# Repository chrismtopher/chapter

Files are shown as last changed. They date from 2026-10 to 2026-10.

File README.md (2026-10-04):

# Chapter Player for Audiobookshelf



A simple Raspberry Pi friendly Chapter player for Audiobookshelf.

Current release: **[v0.3.11](https://github.com/chrismtopher/chapter/releases/tag/v0.3.11)**

Chapter Player for Audiobookshelf is an independent third-party project and is not affiliated with or supported by the Audiobookshelf project.

Chapter is a native Linux appliance app built with Python and GStreamer. It signs in to Audiobookshelf with a dedicated user account, securely stores the server-issued tokens, shows a simple two-line OLED library and playback interface, resumes from Audiobookshelf progress, and syncs progress back while listening.

The target device is a small enclosure with a 2.08 inch SH1122 SPI OLED, two KY-040 rotary encoders, a MAX98357A I2S amp, and an internal speaker.

## Quick Install

Flash Raspberry Pi OS Lite onto a Raspberry Pi Zero 2 W/WH, enable SSH, and connect to the Pi. The recommended setup username is `chapter` and hostname is `chapter-player`.

Then run:

```bash
curl -fsSL https://raw.githubusercontent.com/chrismtopher/chapter/v0.3.11/scripts/install-raspberry-pi.sh | bash
sudo reboot
```

The installer handles the software setup:

- system packages
- project clone/update in `/home/chapter/audiobookshelf-player`
- SPI enablement
- MAX98357A I2S audio and ALSA config
- setup web page service
- OLED service and boot splash
- port 80 setup-page proxy
- captive portal DNS helper
- Bluetooth unblock helper
- BlueALSA Bluetooth audio backend

For the complete hardware, flashing, wiring, setup, and troubleshooting walkthrough, see the [Raspberry Pi Zero 2 W install guide](docs/raspberry-pi-zero-2w-install.md).

## Hardware

Recommended build:

- Raspberry Pi Zero 2 WH, or Raspberry Pi Zero 2 W with a soldered 40-pin header
- 16 GB or larger microSD card
- Regulated 5 V power supply rated for at least 2 A; see the install guide for the Adafruit 5993's 1.5 A power-path limitation
- 2.08 inch 256x64 SH1122 SPI OLED
- Two KY-040 rotary encoder modules
- MAX98357A I2S mono amplifier breakout
- 4 ohm speaker
- 1.5 A inline fuse on the USB-C 5 V positive lead
- 3 mm warm-white power indicator LED for the lower-right front-cover hole
- Cross-connect wires for component wiring

The wiring tables are in the [install guide](docs/raspberry-pi-zero-2w-install.md#wire-the-hardware).

Purchase links for the recommended parts are in [docs/hardware-links.md](docs/hardware-links.md).

Printable case files are in [hardware/case](hardware/case).

## Setup

After installation and reboot, open the setup page from a phone or computer on the same network:

```text
http://chapter-player.local
```

If the player is not connected to Wi-Fi, it starts an open setup hotspot:

```text
Network:  Chapter-Setup
Password: none
Page:     http://10.42.0.1
```

The setup page lets you enter your Wi-Fi details and log the player into Audiobookshelf. Create a dedicated Audiobookshelf user for the player and restrict that user to the appropriate library or tags.

For a simple handout, see the [first boot one-sheet](docs/first-boot-one-sheet.md).

For a package-style quick start card, open the [PDF](docs/first-boot-quick-start.pdf) or [JPG](docs/first-boot-quick-start.jpg).

## Controls

- Turn the Select knob to browse books.
- Click the Select knob to choose.
- Turn the Volume knob to change volume.
- Click the Volume knob to mute or unmute.
- Hold the Volume knob for 10 seconds to show the setup address.
- Hold the Select knob for 3 seconds to open the Bluetooth menu.
- In the Bluetooth menu, turn the Select knob to choose `Enable`, `Disable`, `Pair`, `Unpair`, or `Back`, then click to select.
- To pair a speaker or headphones, put the device in pairing mode, choose `Pair`, wait for the device list, turn to the device name, and click to connect.
- Parents can enable `Spoken navigation` on the Settings tab to have the player read highlighted book titles and controls aloud. It is disabled by default.
- With spoken navigation enabled, Volume-knob changes are announced at 10% intervals, volume stops at 10%, and pressing the Volume knob does not mute the player.

## Features

- Two-line SH1122 OLED library and playback UI
- Select and Volume rotary controls
- Internal speaker playback through GStreamer
- Audiobookshelf login through the local setup page
- Admin web page player controls, including play/pause and volume
- Configurable library ordering by title or author last name
- Optional offline spoken navigation for book titles and controls using a tuned eSpeak NG voice
- System-tab software update checks and one-button stable release installation
- Resume from Audiobookshelf progress
- Periodic progress sync back to Audiobookshelf
- Multi-file audiobook playback
- Continue/start-over prompt when a book has listening history
- Wi-Fi setup fallback hotspot

## Security

The administration page is intentionally passwordless and is intended only for a trusted private home network. Anyone who can reach it can control or reset the player. Do not expose the player to the internet, configure router port forwarding, or connect it to an untrusted network.

CSRF protection prevents unrelated websites from submitting commands through your browser, but it does not authenticate people already connected to the same network. Use a dedicated, restricted Audiobookshelf account for the player. See the full [security policy](SECURITY.md) for details and vulnerability-reporting instructions.

## Development

Run the test suite with:

```bash
python3 -m unittest discover -s tests
```

Run the isolated Raspberry Pi OS Lite installer simulation with:

```bash
tests/mock_raspberry_pi_install.sh
```

See [docs/appliance-design.md](docs/appliance-design.md) for hardware notes, UI behavior, and future direction.

Release history is recorded in [CHANGELOG.md](CHANGELOG.md).

## License

This project is open source under the terms of the [MIT License](LICENSE).

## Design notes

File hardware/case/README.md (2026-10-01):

# Chapter Case

Printable STL files for the Chapter Player enclosure.

## Files

- [stl/chapter-case-front-v5.stl](stl/chapter-case-front-v5.stl) - front case shell
- [stl/chapter-case-back-v5.stl](stl/chapter-case-back-v5.stl) - back case shell
- [stl/chapter-case-knob-v5.stl](stl/chapter-case-knob-v5.stl) - rotary encoder knob

## Assembly Diagrams

- [case-top-select-volume-reference.png](case-top-select-volume-reference.png) - CAD reference showing the top of the case and the `SELECT` and `VOLUME` labels
- [case-front-cover-backside-oled-layout.jpg](case-front-cover-backside-oled-layout.jpg) - annotated CAD view of the back side of the front cover showing OLED installation
- [case-back-interior-layout.jpg](case-back-interior-layout.jpg) - annotated CAD view into the case back showing heat press insert bosses and hardware mounting areas
- [case-rotary-encoder-mount-layout.jpg](case-rotary-encoder-mount-layout.jpg) - annotated CAD view from the x=0/front-side angle showing the two KY-040 rotary encoder mounts

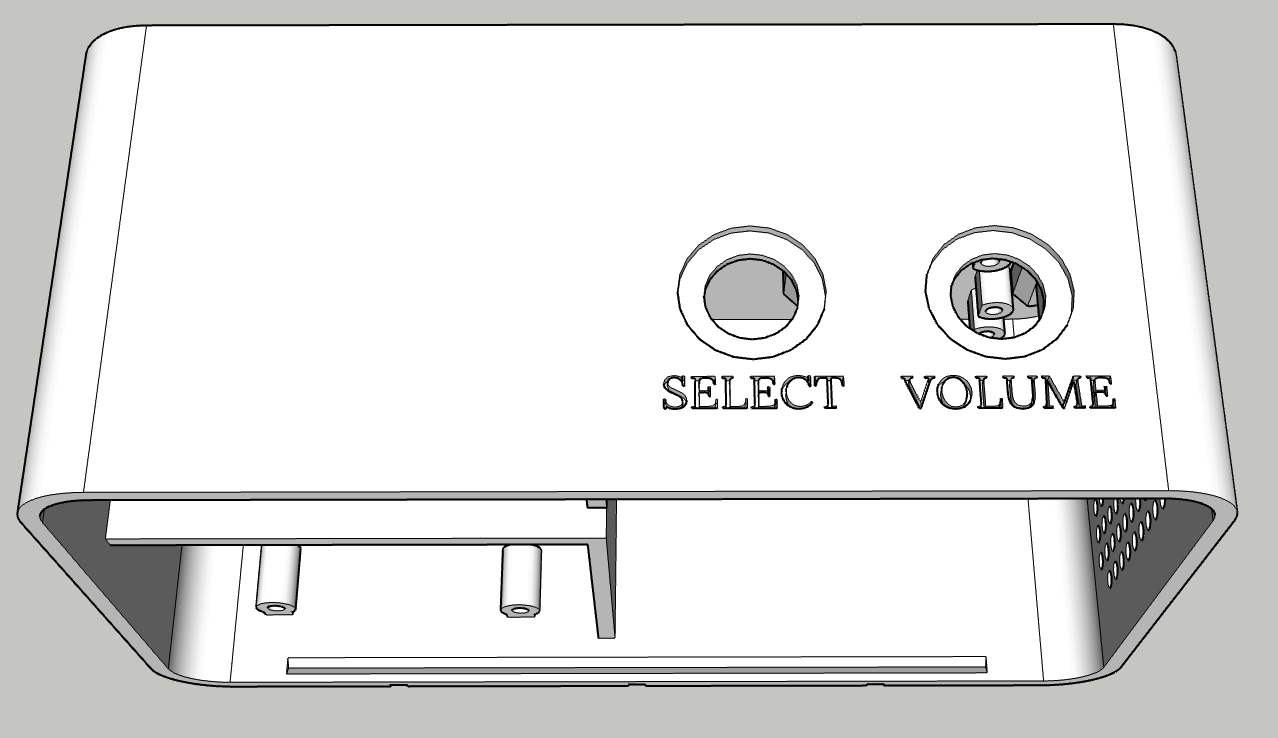
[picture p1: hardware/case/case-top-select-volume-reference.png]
Top of case with Select and Volume labels


Use this CAD view as the reference for the top of the finished case. The left opening is labeled `SELECT` and the right opening is labeled `VOLUME`, matching the control names used throughout the Chapter documentation.

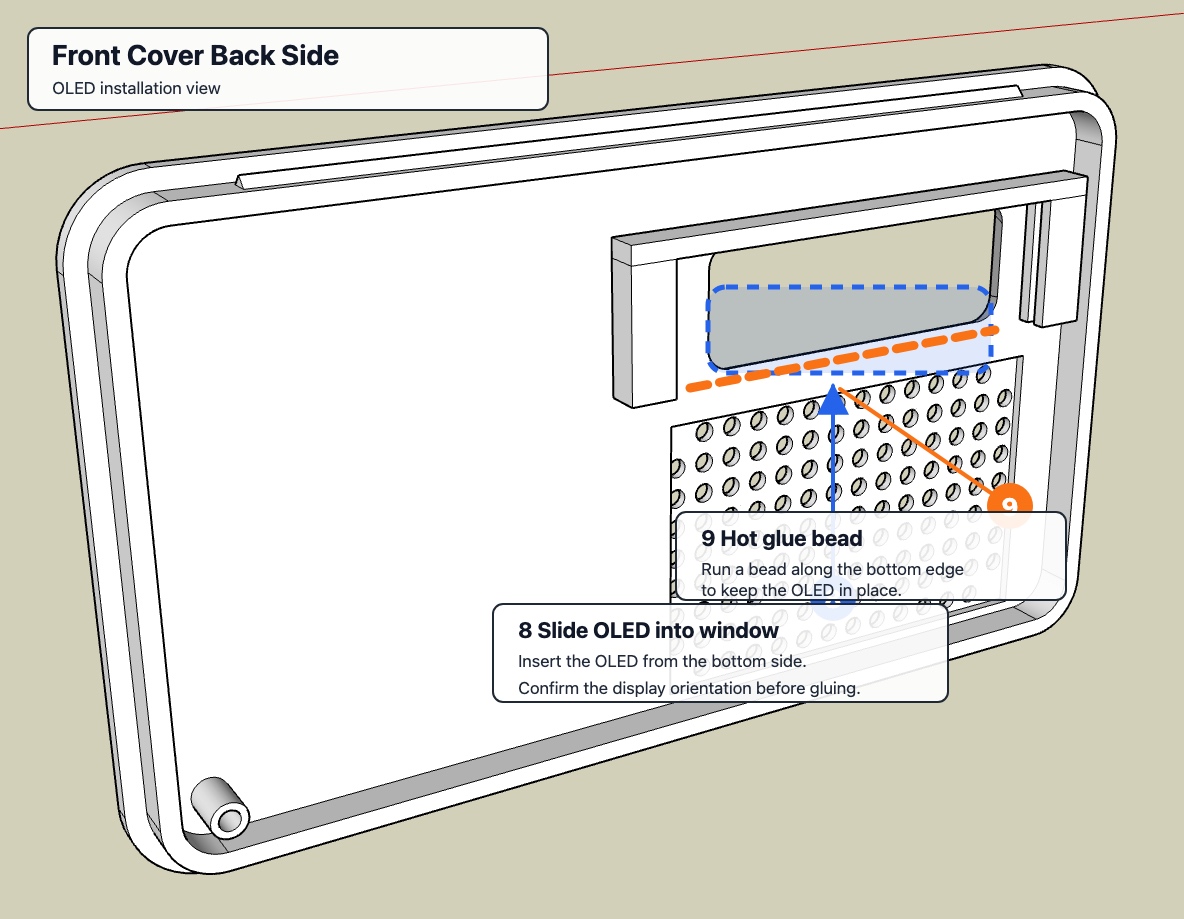
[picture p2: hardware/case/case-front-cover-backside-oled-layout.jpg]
Front cover back side OLED layout


In the front cover back-side diagram, blue `8` marks the OLED window. Slide the OLED into the window from the bottom. After you confirm the OLED is in the correct orientation, run a small bead of hot glue along the bottom edge, marked in orange as `9`, to keep it in place.

The small hole at the lower-right of the front cover, as viewed from the outside, is for the 3 mm warm-white power indicator LED. Insert the LED into the hole from the back of the cover and secure it with a small dab of hot glue. The build uses the 5-6 V [Dioramo 13240](https://dioramo.com/products/13240); see the [install guide](../../docs/raspberry-pi-zero-2w-install.md#power-indicator-led) for its power wiring.

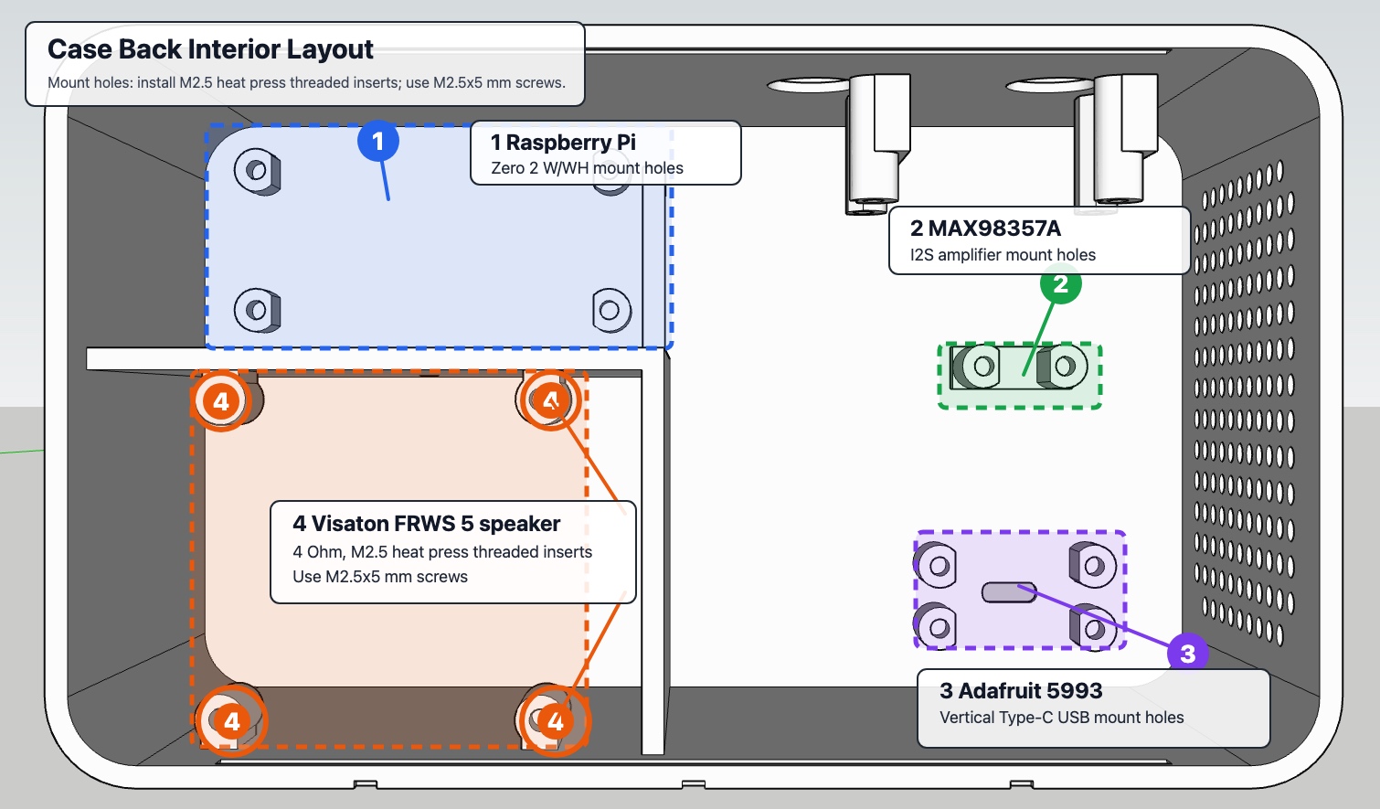
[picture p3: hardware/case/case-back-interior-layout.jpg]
Case back interior layout


In the diagram, orange `4` marks the speaker mounting bosses for a Visaton FRWS 5 - 4 Ohm speaker. Install M2.5 heat press threaded inserts in the highlighted mounting holes and use M2.5x5 mm screws for mounting components.

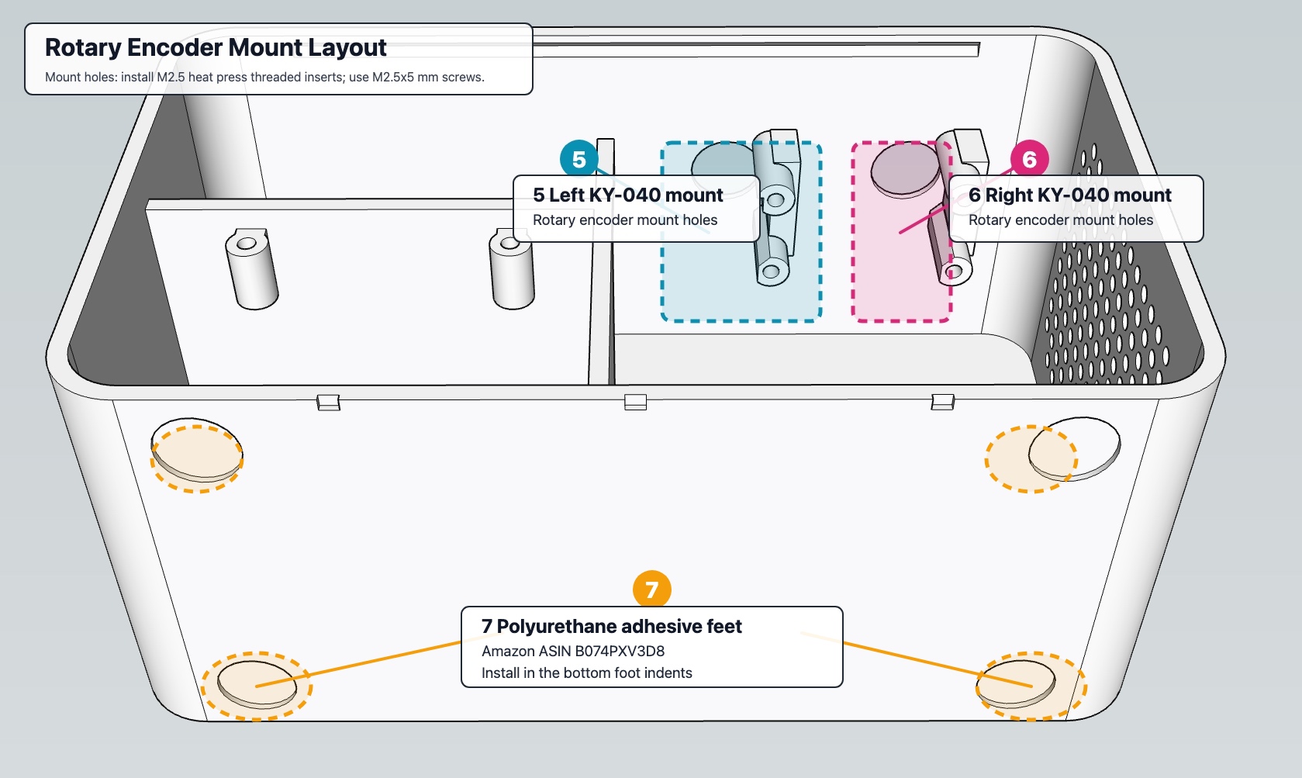
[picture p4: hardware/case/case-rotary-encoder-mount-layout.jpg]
Rotary encoder mount layout


In the rotary encoder diagram, `5` and `6` mark the KY-040 module mounts for the Select and Volume knobs on the inner front wall.

Orange `7` marks the bottom foot indents. Install polyurethane adhesive feet in those indents; the build uses [Amazon ASIN B074PXV3D8](https://www.amazon.com/dp/B074PXV3D8?th=1).

The annotated JPGs use the CAD screenshots in [images/](images/) as their source views.

## Installing The Front Cover

Treat the front cover as the final assembly step. Before installing it, complete the wiring and software tests and confirm that the display, Select knob, Volume knob, speaker, power indicator, Wi-Fi, and playback all work correctly.

1. Arrange the internal wiring so no wire can be pinched between the front cover and the back of the case.
2. Place the front cover over the back of the case and align their edges.
3. Start at either the left or right side; engaging one side first is easier than trying to snap the entire cover into place at once.
4. Work around the perimeter with even hand pressure until the remaining tabs snap into place.
5. Check that the seam is even and fully seated on every side.

If a section is difficult to insert, a thin plastic spudger or similar non-marring tool can provide gentle leverage between the cover and the back of the case. Do not force the cover, use a metal screwdriver, or pry near wiring and printed snap tabs; stop and check alignment or trapped wires instead.

## Notes

These files are provided as the v5 case export. They are intended for the Raspberry Pi Zero 2 W/WH build described in the main install guide.

The exact print orientation, supports, material, and slicer settings may depend on your printer. If you remix the case, STEP or source CAD files are especially helpful for other builders.

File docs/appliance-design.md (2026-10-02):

# Appliance Design

This project is a small kid-friendly audiobook appliance. The released build works on its own with a built-in speaker and can optionally send audio to a paired Bluetooth speaker or headphones. Sonos and AirPlay output are not currently implemented.

## Recommended Hardware

### Core Device

- Lowest-cost target: Raspberry Pi Zero 2 W
- Easier development target: Raspberry Pi 4, 2GB RAM or better
- Raspberry Pi OS Lite
- 16GB or 32GB A1/A2 microSD card
- Good 5V power supply sized for the Pi, OLED, and speaker amp

Moving from a graphical touchscreen to a two-line OLED makes the Pi Zero 2 W realistic. A Pi 4 is still nicer while developing, but it is no longer required for the finished appliance.

### Display

- D-FLIFE 2.08 inch SH1122 SPI OLED
- 256x64 pixels
- 4-wire SPI
- 3.3V logic and power
- Two-line UI: title on top, context/action on bottom

This display changes the product shape: cover art should not be shown on-device. The app can still use Audiobookshelf cover metadata later for a web admin view or companion app.

### Controls

Use two KY-040 rotary encoder modules, labeled `Select` and `Volume` on the case:

- Select knob: browse books, choose continue/start-over, play/pause, and confirm chapter navigation.
- Volume knob: turn for volume, short-click for mute/unmute, and hold for 10 seconds to show the setup IP.

The KY-040 has `CLK`, `DT`, `SW`, `+`, and `GND` pins. Power each module from the Pi's 3.3V rail, not 5V, so its pull-ups never expose a Raspberry Pi GPIO input to 5V. If clockwise/counter-clockwise feels reversed after mounting, either swap `CLK` and `DT` or set the encoder's `reversed` flag in software.

### Internal Speaker

Use an I2S amplifier board rather than Bluetooth. I2S keeps the build self-contained and works cleanly even on Pi models with no analog audio jack.

Recommended parts:

- MAX98357A I2S mono amplifier breakout
- One Visaton FRWS 5 - 4 Ohm full-range speaker
- Small speaker grille or perforated enclosure area

For audiobook voice playback, one internal mono speaker is enough. A stereo I2S amp or bonnet is fine too, but it is not required.

### Speaker Chamber

Target a sealed chamber of about 0.2 to 0.35 liters net internal volume for the Visaton FRWS 5 - 4 Ohm. Bigger is fine if the enclosure allows it; smaller still works for speech, but it will sound thinner and more constrained.

Good internal dimensions:

- 70 mm x 70 mm x 45 mm = 0.22 liters
- 80 mm x 70 mm x 45 mm = 0.25 liters
- 80 mm x 80 mm x 50 mm = 0.32 liters

Keep the chamber empty except for the speaker and speaker wires. A small amount of acoustic damping material is okay if the chamber sounds boxy, but keep it away from the back of the speaker cone. Seal the speaker gasket and the wire pass-through.

## Playback Architecture

```text
Audiobookshelf API
    |
    | library, metadata, sessions, progress
    v
Kids Player UI
    |
    +-- OLED: SH1122 SPI two-line display
    |
    +-- Inputs: Select knob + Volume knob
    |
    +-- Local output: GStreamer -> I2S internal speaker
    |
    +-- Optional output: paired Bluetooth speaker or headphones
```

## Two-Line UI

### Library

```text
Top:    audiobook title
Bottom: By author
```

Turn the Select knob to move through titles. Click it to open the selected title.

### Continue or Start Over

```text
Top:    audiobook title
Bottom: Home | Continue | Start over
```

When the selected book has listening history, `Continue` is the default selection. Turn the Select knob to move between `Home`, `Continue`, and `Start over`, then click to choose. If the book has no listening history, show only `Home` and `Start`.

### Playing

```text
Top:    scrolling chapter title with remaining time at the upper-right
Bottom: Home | Prev | Play/Pause | Next
```

The Select knob moves left and right through the action row, stopping at the edges. Click it to choose the focused action. `Play/Pause` is focused by default when playback starts. `Prev` and `Next` ask for confirmation before changing chapters. Returning to `Home` while audio continues playing automatically returns to this playback screen after five seconds without input.

Long chapter titles scroll horizontally while the remaining-time display and bottom action row stay fixed.

### Chapter Confirmation

```text
Top:    Are you sure you want to listen to the previous/next chapter?
Bottom: Yes | No
```

Turn the Select knob to switch between `Yes` and `No`. Click to confirm. The prompt returns to the playback screen after five seconds without input.

### Volume

The Volume knob is global:

- Turn clockwise: volume up
- Turn counter-clockwise: volume down
- Short click: mute/unmute
- Hold for 10 seconds: show the setup web page IP address on the OLED for 5 seconds

The long hold should not also toggle mute.

When volume is adjusted, replace the current OLED screen with a temporary volume overlay:

```text
Top:    Volume, or Muted at zero
Bottom: rounded graphical fill bar
```

The overlay should update on every volume step, then return to the previous screen after a short timeout.
Each additional volume adjustment refreshes the timeout, so the overlay remains visible for a few seconds after the user stops turning the knob.

## Suggested GPIO Pinout

This pinout avoids the I2S pins used by the MAX98357A amplifier. `GPIO` values use BCM numbering; `Physical Pin` values identify positions on the 40-pin header.

| Part | Signal | GPIO | Physical Pin |
| --- | --- | ---: | ---: |
| OLED | VCC | 3.3V | 1 |
| OLED | GND | GND | 6 |
| OLED | SCLK | GPIO11/SCLK | 23 |
| OLED | SDIN/MOSI | GPIO10/MOSI | 19 |
| OLED | CS | GPIO8/CE0 | 24 |
| OLED | DC | GPIO24 | 18 |
| OLED | RES | GPIO25 | 22 |
| Select knob KY-040 | + | 3.3V | 1 |
| Select knob KY-040 | GND | GND | 9 |
| Select knob KY-040 | CLK | GPIO5 | 29 |
| Select knob KY-040 | DT | GPIO6 | 31 |
| Select knob KY-040 | SW | GPIO13 | 33 |
| Volume knob KY-040 | + | 3.3V | 17 |
| Volume knob KY-040 | GND | GND | 14 |
| Volume knob KY-040 | CLK | GPIO12 | 32 |
| Volume knob KY-040 | DT | GPIO16 | 36 |
| Volume knob KY-040 | SW | GPIO26 | 37 |
| I2S amp | VIN | 5V | 2 or 4 |
| I2S amp | GND | GND | Any available GND pin |
| I2S amp | BCLK | GPIO18 | 12 |
| I2S amp | LRCLK | GPIO19 | 35 |
| I2S amp | DIN | GPIO21 | 40 |
| I2S amp | SD | Not connected | - |
| Speaker | + / - | I2S amp speaker output | - |

The two KY-040 modules can share 3.3V and ground rails. The code also enables Raspberry Pi internal pull-ups; this is harmless when the KY-040 module already has pull-ups, provided the module is powered from 3.3V.

The MAX98357A speaker output is differential. Connect the speaker only between the amplifier's `+` and `-` speaker terminals; never connect either speaker terminal to Raspberry Pi ground. Leave the amplifier `SD` pad disconnected in the released build.

## USB-C Power

Use the Adafruit 5993 vertical USB-C breakout as the appliance's rear power port. Chapter uses this connector for power only; leave `D+`, `D-`, `CC`, and `SBU` unwired.

For power, solder the positive lead to either Adafruit 5993 pad labeled `VBUS` and the negative lead to either pad labeled `GND`. Its two breakout rows duplicate the same connections, so either matching pair may be used. `VBUS` carries raw USB 5 V. Use red wire for `VBUS` and black wire for `GND`, and do not use the `CC`, `SBU`, `D+`, or `D-` pads as power connections.

| Adafruit 5993 pad | Raspberry Pi Zero 2 WH | Notes |
| --- | --- | --- |
| `VBUS` (+5 V) | 5V header pin 2 or 4, or 5V test pad | Positive power lead; install a 1.5 A fuse in series. |
| `GND` (-) | GND header pin 6, or GND test pad | Negative power lead; connect to the Pi and amplifier common ground. |

Recommended fuse options:

- Bourns `MF-MSMF150-2`, 1.5A hold / 3A trip, 6V, 1812 SMD
- Littelfuse `1812L150ZR`, 1.5A hold / 3A trip, 8V, 1812 SMD
- Inline holder: [Amazon ASIN B0813Q4S6P](https://www.amazon.com/dp/B0813Q4S6P), fitted with the included 1.5 A fast-blow 5x20 mm fuse

Wire the fuse in series with USB-C `VBUS`, before the Pi and amplifier:

```text
USB-C VBUS -> 1.5 A fuse -> optional power switch -> Pi 5V / amp 5V
USB-C GND  -> Pi GND / amp GND
```

Do not put the fuse in series with `GND`, `D+`, or `D-`.

Adafruit specifies this breakout arrangement for 5 V at up to 1.5 A. Raspberry Pi recommends a 2 A-capable supply for the Zero 2 W, so the tested 5993 is the limiting part of this power path. If Chapter reports undervoltage, reboots at high volume, or behaves unreliably, replace the input path with a regulated 5 V solution rated for at least 2 A.

Powering through a 5 V header pin bypasses the Pi's normal input protection. Verify polarity and voltage before connecting power, and never power the appliance through the 5993 and the Pi's original `PWR IN` micro-USB port simultaneously.

The lower-right hole in the front cover is for a 3 mm warm-white power indicator. Insert the LED from the back and hold it in place with a small dab of hot glue. Splice it as a parallel branch across fused 5 V and ground between the USB-C port and Pi; never put the LED in series with the Pi's supply. The indicator lights immediately when USB power is present, before the OLED service is ready.

The specified [Dioramo 13240](https://dioramo.com/products/13240) is rated for 5-6 V and includes its current-limiting resistor. Connect its white-marked anode wire directly to fused 5 V and its black cathode wire to ground; no additional resistor is required.

The USB-C connector supplies power only. Continue to use Wi-Fi or the Pi's original USB data port for servicing the appliance.

## Setup Web Page

The player exposes a local setup page on port `47831`. The appliance can also install a port `80` proxy so people can browse without typing a port:

```text
http://raspberrypi.local
```

On boot, the setup service should run with Wi-Fi fallback enabled:

```bash
python3 -m abs_kids_player.setup_server --ensure-wifi
```

This depends on NetworkManager's `nmcli`. The automated installer installs the setup page as a root-owned system service so it can manage Wi-Fi and start after reboot without an SSH session.

If no Wi-Fi connection is active, the player starts a temporary setup hotspot:

```text
Network:  Chapter-Setup
Password: none
Page:     http://10.42.0.1
```

While the hotspot is active, the OLED should show:

```text
Top:    Connect to Chapter-Setup
Bottom: Browse to http://10.42.0.1
```

The setup page accepts home Wi-Fi credentials. After submitting, the player waits briefly so the browser can receive the response, then asks NetworkManager to join the selected Wi-Fi network.

The setup hotspot should be an open network. To improve captive portal behavior, install the NetworkManager dnsmasq shared-mode config from `deploy/audiobookshelf-player-captive-portal-dnsmasq.conf`. It resolves HTTP browser traffic on the setup hotspot to `10.42.0.1`, and the port `80` proxy returns the setup page for arbitrary HTTP GET paths. This should trigger captive portal prompts on many phones and laptops. HTTPS sites cannot be transparently redirected, so the OLED still shows the direct setup URL as a reliable fallback.

The page logs the player into Audiobookshelf with the selected user's username and password. The password is not stored. The player persists:

- Audiobookshelf server URL
- Returned access and refresh tokens
- Audiobookshelf username
- Resolved library ID

This lets a parent change which Audiobookshelf user the appliance uses without attaching a keyboard and display to the Pi.

To reveal the address without a monitor, hold the Volume knob for 10 seconds while the unit is powered on. The OLED should show the setup URL, such as `http://192.168.1.42`, for 5 seconds and then return to the previous screen.

The web interface shows separate status rows for Wi-Fi, Audiobookshelf, Bluetooth, and current playback. Its System tab shows the installed version, available software updates, reboot control, and device-reset control. The `/health` route exposes machine-readable status for diagnostics.

## Enclosure Notes

- Keep the speaker chamber separate from the Pi where possible.
- Leave airflow around the Pi and amplifier.
- Put the OLED, speaker grille, wordmark, and power indicator on the front cover.
- Mount the two rotary encoders on the top panel and label them `SELECT` and `VOLUME`.
- Keep ports reachable for service, but hide them from everyday use.
- Add a small service hatch for the microSD card if possible.

## Render Reference

Use the current 3D printed prototype as the visual reference for future renders:

- Matte off-white PLA body and front cover with visible fine print texture.
- Warm tan/brown printed knobs with ridged/scalloped edges and textured top faces.
- Two similarly sized, low-profile knobs on the top panel: `SELECT` on the left and `VOLUME` on the right.
- OLED window on the upper-left/front with a black recessed display area and rounded rectangular cutout.
- Lowercase `chapter` wordmark in warm brown on the upper-right/front.
- Small 3 mm power-indicator opening at the lower-right of the front cover.
- Speaker grille on the lower-left/front, made from a dense grid of round holes.
- Matching side ventilation/speaker-style hole grid on the right side panel.
- Soft rounded outer corners and a gently rounded front perimeter.
- Keep the render grounded as a real printed object, not a perfectly smooth injection-molded product.

## References

- SH1122 OLED module specs: https://www.displaymodule.com/products/2-08-inch-oled-graphic-monochrome-display-256x64-with-spi
- KY-040 rotary encoder module reference: https://componentindex.net/components/rotary-encoder/
- KY-040 Raspberry Pi wiring reference: https://sensorkit.joy-it.net/en/sensors/ky-040
- Adafruit MAX98357A Raspberry Pi wiring: https://learn.adafruit.com/adafruit-max98357-i2s-class-d-mono-amp/raspberry-pi-wiring
- Adafruit 5993 USB-C breakout: https://www.adafruit.com/product/5993

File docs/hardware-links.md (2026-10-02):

# Hardware Links

These links are the parts used for the Chapter Player build. Quantities are for one player.

Links may change over time; equivalent parts should also work if they match the specs in the install guide and wiring tables.

## Electronics

| Part | Qty | Link | Notes |
| --- | ---: | --- | --- |
| Raspberry Pi Zero 2 W/WH | 1 | [Adafruit product 6008](https://www.adafruit.com/product/6008) | Use a WH board or add a soldered 40-pin header. |
| 2.08 inch SH1122 SPI OLED | 1 | [Amazon ASIN B0D1V5YBXC](https://www.amazon.com/dp/B0D1V5YBXC) | 256x64 SPI OLED. |
| KY-040 rotary encoder module | 2 | [Amazon ASIN B07T3672VK](https://www.amazon.com/dp/B07T3672VK) | One for the Select knob and one for the Volume knob. |
| MAX98357A I2S mono amplifier breakout | 1 | [Amazon ASIN B0GF67KXC3](https://www.amazon.com/dp/B0GF67KXC3?th=1) | Drives the internal speaker. |
| Adafruit 5993 vertical USB-C breakout | 1 | [Adafruit product 5993](https://www.adafruit.com/product/5993) | Rear USB-C power port. Solder positive power to `VBUS` and negative power to `GND`; either duplicate pad row may be used. Leave all data pads disconnected. Adafruit specifies up to 1.5 A for this breakout arrangement. |
| Inline fuse holder and fuse | 1 | [Amazon ASIN B0813Q4S6P](https://www.amazon.com/dp/B0813Q4S6P) | Install the included **1.5 A fast-blow 5x20 mm fuse** in series on the positive lead. The linked assortment also contains unsuitable higher-current fuses, so verify the marking before installation. |
| 3 mm warm-white power indicator LED | 1 | [Dioramo 13240](https://dioramo.com/products/13240) | Fits the lower-right front-cover hole. This 5-6 V version includes its current-limiting resistor and connects directly across Chapter's fused 5 V and ground leads. |
| Visaton FRWS 5 - 4 Ohm full-range speaker | 1 | [Parts Express 292-7820](https://www.parts-express.com/Visaton-FRWS5-4-2-Full-Range-Speaker-4-Ohm-292-7820?quantity=1) | Internal speaker. |
| Cross-connect wiring | 1 set | [Amazon ASIN B01EV70C78](https://www.amazon.com/dp/B01EV70C78?th=1) | Used for wiring between the Raspberry Pi and the display, encoders, amp, USB-C board, and fuse. |

## Case Hardware

| Part | Qty | Link | Notes |
| --- | ---: | --- | --- |
| Polyurethane adhesive feet | 4 | [Amazon ASIN B074PXV3D8](https://www.amazon.com/dp/B074PXV3D8?th=1) | Install in the bottom foot indents shown in the case diagram. |
| M2.5 heat press threaded inserts | 18 | Source from your preferred hardware supplier | Install in the highlighted component mounting holes. |
| M2.5x5 mm screws | 18 | Source from your preferred hardware supplier | Used for mounting components into the heat press inserts. |
| Printed case front, back, and knobs | 1 set | [Case STL files](../hardware/case/) | Print the v5 case files from the repository. |

## Common Build Supplies

- 16 GB or larger microSD card.
- Regulated 5 V power supply rated for at least 2 A; 2.5 A is also suitable. The specified Adafruit 5993 remains limited to the 1.5 A arrangement described in the install guide.
- Cross-connect wires or soldered hookup wire.
- Soldering tools if using a Raspberry Pi Zero 2 W without a pre-soldered header.

See the [Raspberry Pi Zero 2 W install guide](raspberry-pi-zero-2w-install.md) for wiring tables and setup steps.

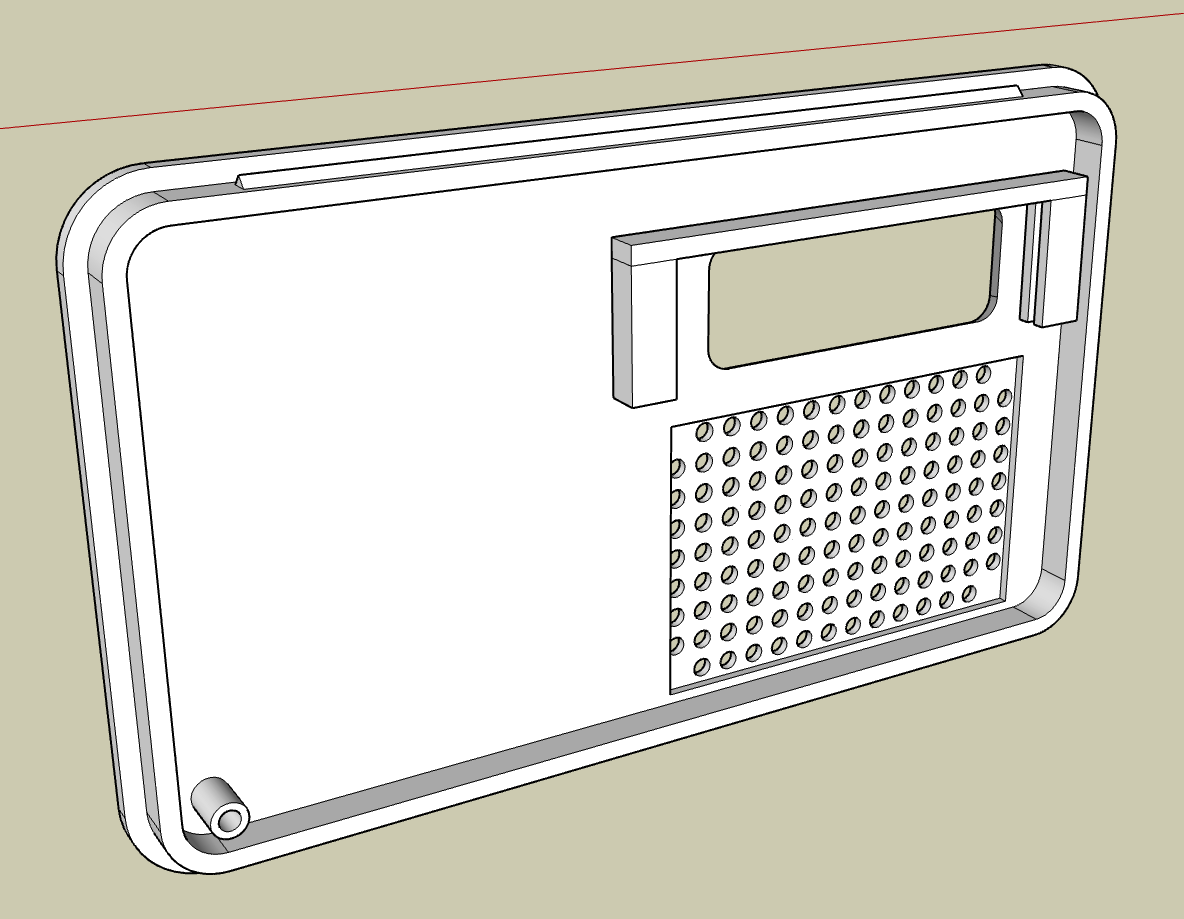
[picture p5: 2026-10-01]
hardware/case/images/case-front-cover-backside-cad-view.png

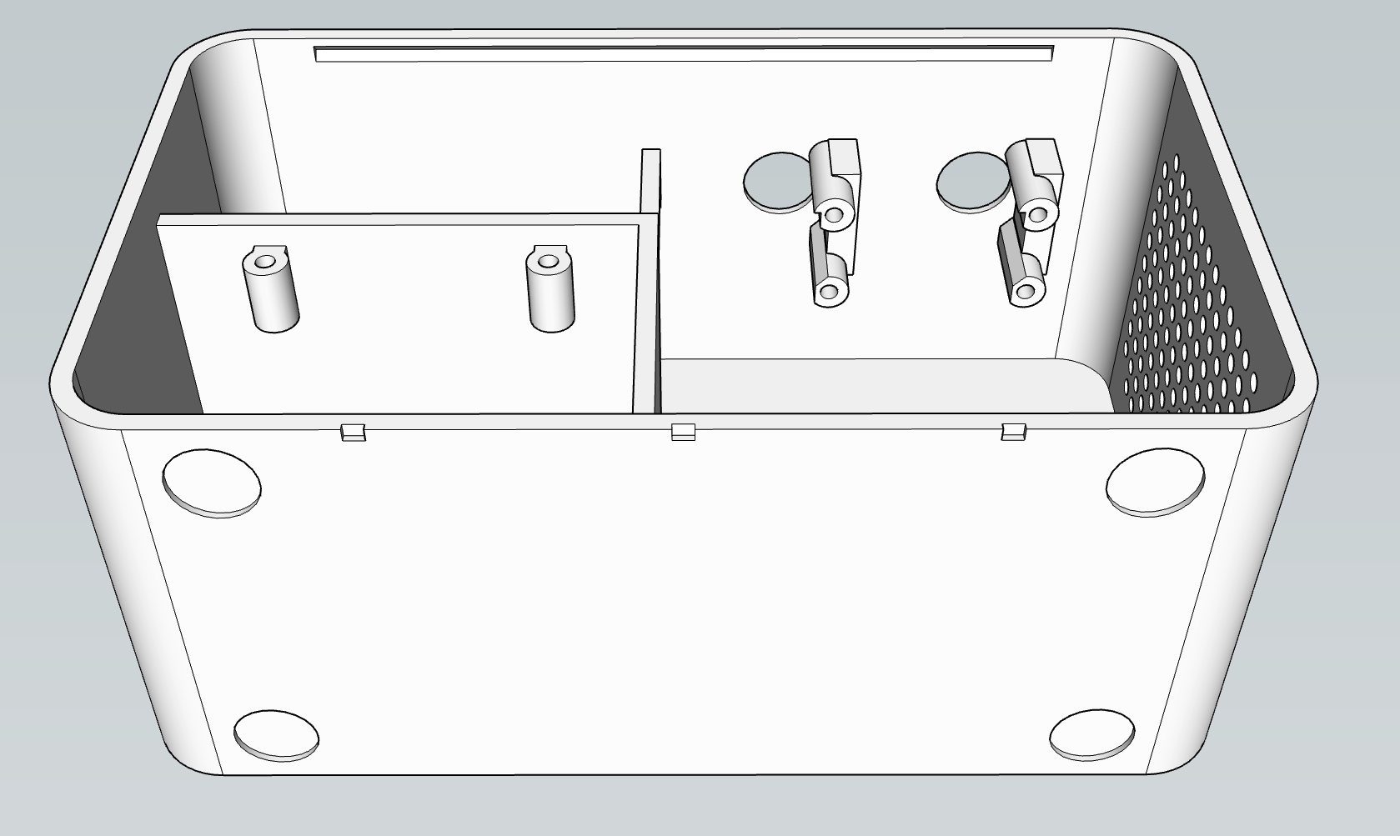
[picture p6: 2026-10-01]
hardware/case/images/case-rotary-encoder-cad-view.png

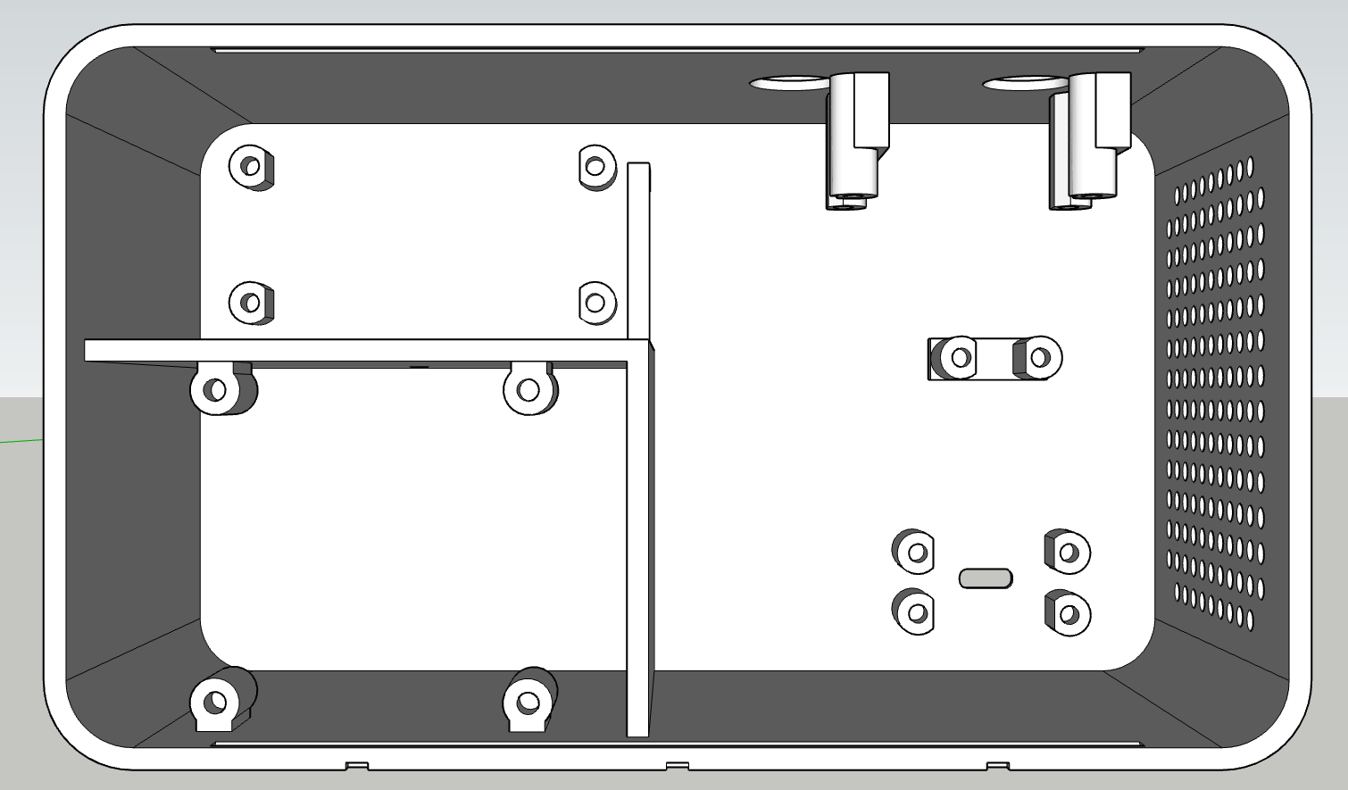
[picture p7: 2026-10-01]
hardware/case/images/case-back-interior-cad-view.png

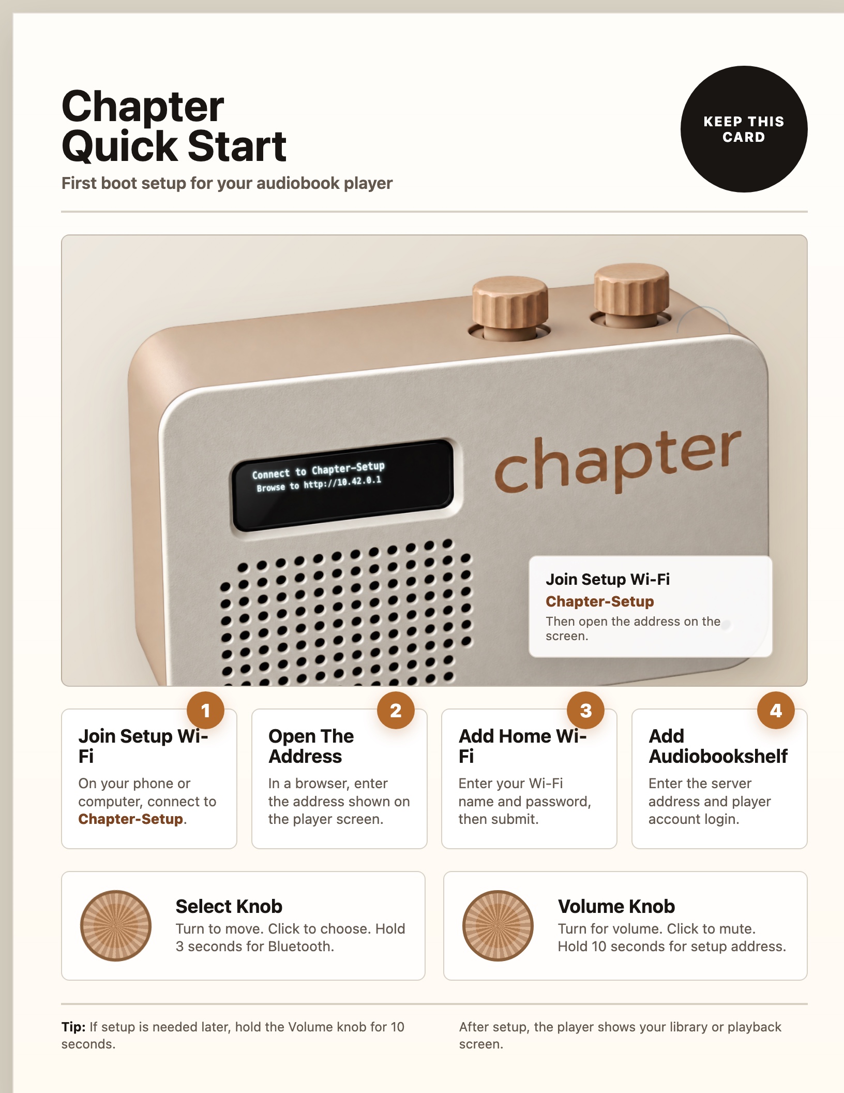
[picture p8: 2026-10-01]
docs/first-boot-quick-start.jpg

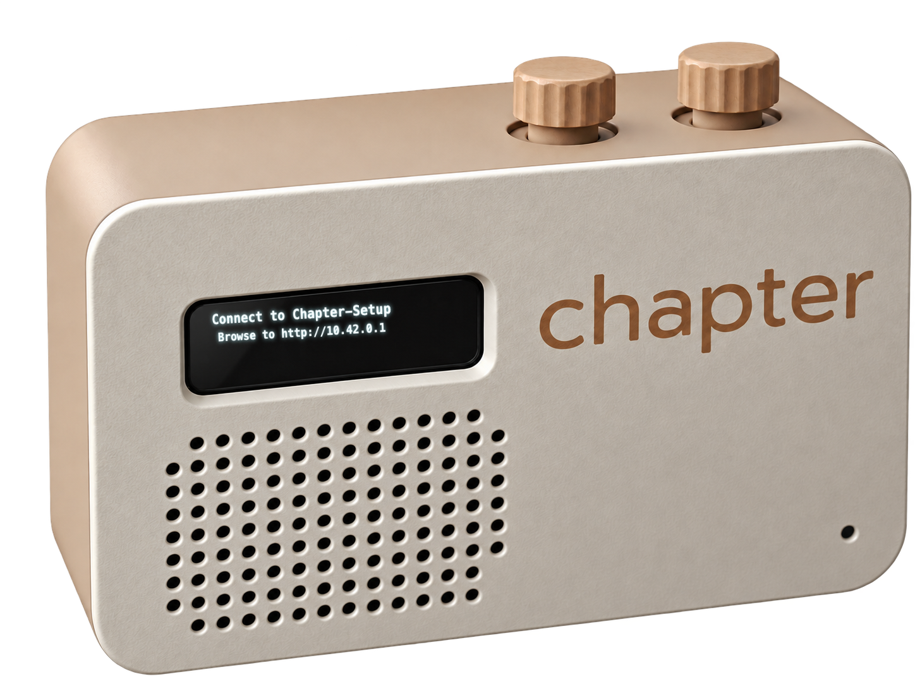
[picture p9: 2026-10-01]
docs/assets/chapter-device-illustrated.png

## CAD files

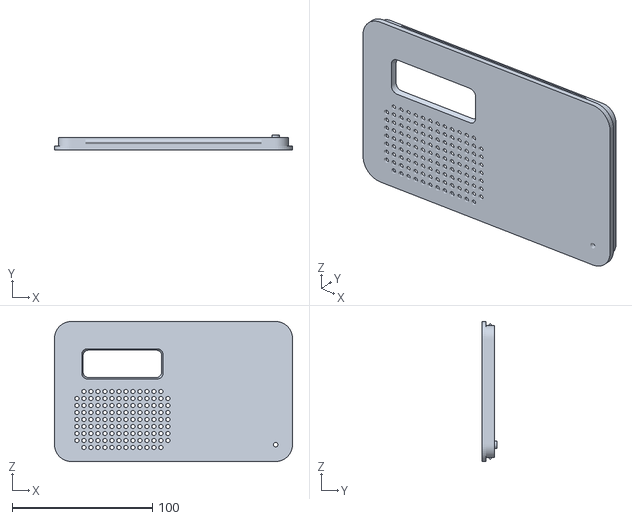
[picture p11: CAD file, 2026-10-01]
hardware/case/stl/chapter-case-front-v5.stl
170.0 x 11.0 x 100.0

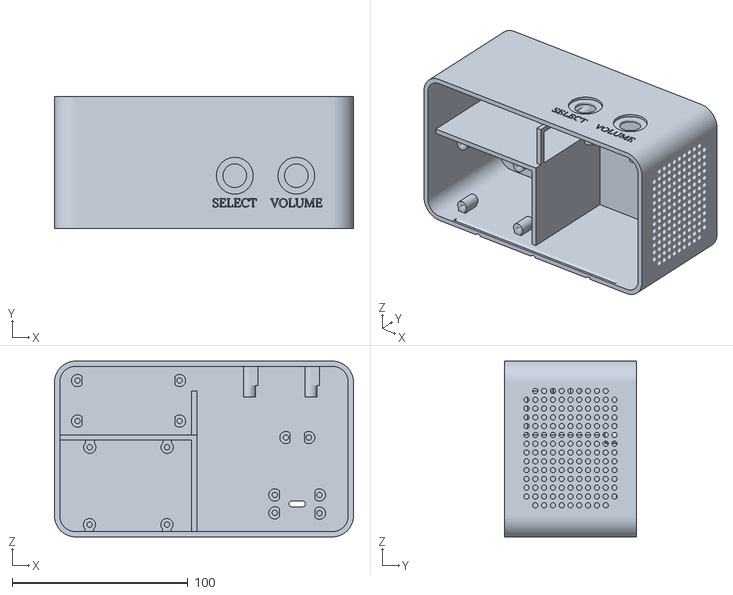
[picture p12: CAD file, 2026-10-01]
hardware/case/stl/chapter-case-back-v5.stl
170.0 x 75.0 x 100.0

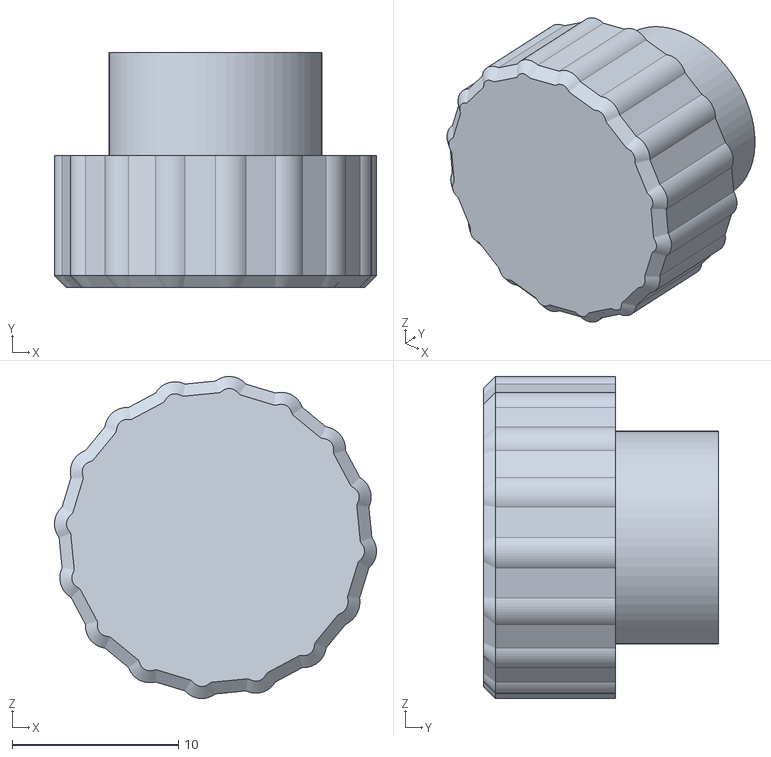
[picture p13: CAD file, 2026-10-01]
hardware/case/stl/chapter-case-knob-v5.stl
19.4 x 14.2 x 19.4

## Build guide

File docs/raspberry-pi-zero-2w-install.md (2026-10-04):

# Raspberry Pi Zero 2 W Install Guide

This guide walks through building a fresh Chapter Player for Audiobookshelf on a Raspberry Pi Zero 2 W or Zero 2 WH.

It assumes you already have an Audiobookshelf server running somewhere on your network or reachable by URL. The player stores an Audiobookshelf user token, so create a dedicated Audiobookshelf user for the player instead of using an admin account.

The software setup is handled by the installer. This guide covers the parts a new builder still needs: buying parts, flashing Raspberry Pi OS Lite, wiring the hardware, running the installer, opening the setup page, and troubleshooting.

## What To Buy

- Raspberry Pi Zero 2 WH, or a Raspberry Pi Zero 2 W plus a soldered 40-pin header.
- 16 GB or larger microSD card. Raspberry Pi OS Lite fits on less, but 16 GB or 32 GB gives you room for updates and logs.
- Good regulated 5 V power supply. Raspberry Pi recommends 2 A capacity for the Zero 2 W; 2.5 A provides additional source-side headroom for the OLED and speaker amp. See the USB-C power note below because the specified Adafruit 5993 breakout is the limiting component.
- 2.08 inch 256x64 SH1122 SPI OLED module.
- Two KY-040 rotary encoder modules.
- MAX98357A I2S mono amplifier breakout.
- 4 ohm speaker.
- 1.5 A inline fuse for the USB-C 5 V positive lead. The linked holder kit includes a suitable 1.5 A fast-blow 5x20 mm fuse.
- 3 mm warm-white power indicator LED for the lower-right front-cover hole. The build uses the 5-6 V [Dioramo 13240](https://dioramo.com/products/13240).
- Cross-connect wires or soldered wiring, plus an enclosure. The build uses [Amazon ASIN B01EV70C78](https://www.amazon.com/dp/B01EV70C78?th=1) for component wiring.

For links to the recommended parts, see the [hardware links](hardware-links.md).

The Pi Zero 2 W Wi-Fi radio is 2.4 GHz only. Use a 2.4 GHz network during setup.

## Flash Raspberry Pi OS

1. Install Raspberry Pi Imager on your computer.
2. Insert the microSD card.
3. In Imager, choose the Pi model and select **Raspberry Pi OS Lite**.
4. Open OS customisation before writing the card.
5. Set the hostname to `chapter-player`.
6. Set the username to `chapter`.
7. Set a password you will remember.
8. Configure your 2.4 GHz Wi-Fi network and country.
9. Enable SSH.
10. Write the card, insert it into the Pi, and power the Pi.

Wait a few minutes for the first boot. Then connect from your computer:

```bash
ssh chapter@chapter-player.local
```

If `.local` does not resolve on your network, find the Pi's IP address from your router and use:

```bash
ssh chapter@192.168.1.42
```

## Run The Installer

Run this on the Pi:

```bash
curl -fsSL https://raw.githubusercontent.com/chrismtopher/chapter/v0.3.11/scripts/install-raspberry-pi.sh | bash
```

The installer handles the software setup:

- installs required system packages
- creates or updates the `chapter` service user
- clones or updates the project in `/home/chapter/audiobookshelf-player`
- enables SPI for the OLED
- configures the MAX98357A I2S audio overlay
- installs the ALSA mixer config
- installs and enables the setup page service
- installs and enables the OLED service and boot splash
- installs the port 80 setup-page proxy
- installs the captive portal DNS helper
- installs the Bluetooth unblock helper
- installs and enables the BlueALSA Bluetooth audio backend

When it finishes, it will tell you to reboot. If you have not wired the hardware yet, shut the Pi down instead:

```bash
sudo shutdown -h now
```

If the hardware is already wired, reboot:

```bash
sudo reboot
```

To inspect the installer before running it:

```bash
curl -fsSLO https://raw.githubusercontent.com/chrismtopher/chapter/v0.3.11/scripts/install-raspberry-pi.sh
less install-raspberry-pi.sh
bash install-raspberry-pi.sh
```

## Wire The Hardware

Power the Pi off before wiring. Disconnect power, then wire the parts.

All `GPIO` numbers below use Raspberry Pi BCM numbering. The separate `Physical Pin` column identifies the numbered position on the 40-pin header. Do not confuse the two numbering systems.

### OLED

| OLED Pin | Raspberry Pi Signal | Physical Pin |
| --- | --- | ---: |
| `VCC` | 3.3 V | 1 |
| `GND` | GND | 6 |
| `SCL` / `CLK` | GPIO11 / SCLK | 23 |
| `SDA` / `DIN` | GPIO10 / MOSI | 19 |
| `CS` | GPIO8 / CE0 | 24 |
| `DC` | GPIO24 | 18 |
| `RES` / `RST` | GPIO25 | 22 |

### Select Knob (KY-040)

Power the KY-040 from 3.3 V, not 5 V.

| KY-040 Pin | Raspberry Pi Signal | Physical Pin |
| --- | --- | ---: |
| `+` | 3.3 V | 1 |
| `GND` | GND | 9 |
| `CLK` | GPIO5 | 29 |
| `DT` | GPIO6 | 31 |
| `SW` | GPIO13 | 33 |

### Volume Knob (KY-040)

| KY-040 Pin | Raspberry Pi Signal | Physical Pin |
| --- | --- | ---: |
| `+` | 3.3 V | 17 |
| `GND` | GND | 14 |
| `CLK` | GPIO12 | 32 |
| `DT` | GPIO16 | 36 |
| `SW` | GPIO26 | 37 |

### MAX98357A I2S Amp

| Amp Pin | Raspberry Pi Signal | Physical Pin |
| --- | --- | ---: |
| `VIN` | 5 V | 2 or 4 |
| `GND` | GND | 20, 25, 30, 34, or 39 |
| `BCLK` | GPIO18 | 12 |
| `LRC` / `LRCLK` | GPIO19 | 35 |
| `DIN` | GPIO21 | 40 |
| `SD` / `SD_MODE` | Leave disconnected | - |
| Speaker `+` / `-` | Speaker terminals | - |

The default software leaves `SD` / `SD_MODE` alone. That lets the breakout's own mode resistor choose the default mono mix.

The MAX98357A speaker output is differential. Connect the speaker only between the amplifier's `+` and `-` speaker terminals; do not connect either speaker terminal to Raspberry Pi ground. Keep the speaker pair short and, if practical, twisted together and routed away from the OLED and encoder wiring.

### USB-C Power Port And Fuse

If you are using the Adafruit 5993 vertical USB-C breakout as the rear power port, put a 1.5 A inline fuse on the positive 5 V leg coming from the USB-C board before it reaches the Raspberry Pi.

On the Adafruit 5993, solder the positive power lead to either pad labeled `VBUS` and the negative power lead to either pad labeled `GND`. The two breakout rows are duplicates, so either matching `VBUS`/`GND` pair may be used. `VBUS` is the raw 5 V supply from the USB-C connector; do not substitute a `CC`, `SBU`, `D+`, or `D-` pad for either power connection. Using red wire for `VBUS` and black wire for `GND` is recommended.

The build uses the holder and fuse assortment in [Amazon ASIN B0813Q4S6P](https://www.amazon.com/dp/B0813Q4S6P). Install the included **1.5 A fast-blow 5x20 mm fuse** in the holder; do not select one of the higher-current fuses from the assortment.

```text
Adafruit 5993 VBUS pad (+5 V) -> 1.5 A fuse -> Raspberry Pi 5 V pin 2 or 4
Adafruit 5993 GND pad  (-)    -> Raspberry Pi GND
```

Any 5 V branch for the amp should be taken from the fused 5 V side. Do not put the fuse in series with `GND`, `D+`, or `D-`.

Leave `D+`, `D-`, `CC`, and `SBU` unwired in the Chapter build. The Adafruit 5993 is used for 5 V power only.

Adafruit documents this breakout's USB-C current arrangement for 5 V at up to 1.5 A, while Raspberry Pi recommends a 2 A-capable supply for a Zero 2 W by itself. The tested Chapter build normally remains within the breakout's limit, but the 5993 is the power-path constraint. If the Pi reports undervoltage, reboots at high volume, or behaves unreliably, stop using it until you replace the input path with a regulated 5 V solution rated for at least 2 A.

Feeding the Pi through a 5 V header pin bypasses the Pi's normal power-input protection. Verify polarity and voltage before connecting it. Never power Chapter through the Adafruit breakout and the Pi's original `PWR IN` micro-USB port at the same time.

### Power Indicator LED

The small hole at the lower-right of the front cover, viewed from the outside, is for the power indicator. Insert the 3 mm LED into the hole from the back of the cover, then secure it with a small dab of hot glue. Keep glue away from the LED leads and wire joints.

Splice the LED into the USB-C power wiring as a parallel branch after the fuse. It must not be placed in series with either power lead; the Pi must still have a direct fused 5 V and ground connection.

The [Dioramo 13240](https://dioramo.com/products/13240) is rated for 5-6 V and has its current-limiting resistor already wired in. Its white-marked wire is the positive anode and its black wire is the negative cathode, so no additional resistor is required on Chapter's 5 V rail.

```text
Fused USB-C 5 V ----+------------------------> Raspberry Pi 5 V / amp 5 V
                    |
                    +-----------------------> Dioramo 13240 white-marked wire (+)

USB-C GND ----------+------------------------> Raspberry Pi GND / amp GND
                    |
                    +-----------------------> Dioramo 13240 black wire (-)
```

The LED illuminates as soon as USB power is present, providing immediate feedback while the Pi boots and before the OLED service starts.

## First Boot

After the installer has run and the hardware is wired, power the Pi on.

On boot, the OLED should show `chapter` and then one of these:

- setup page address
- setup hotspot instructions
- library home screen

The installer starts the setup page and OLED services automatically on boot.

## Open The Setup Page

If the Pi is on your Wi-Fi, open one of these from a phone or computer on the same network:

```text
http://chapter-player.local
http://<the-pi-ip-address>
```

The setup page also runs directly on port `47831`:

```text
http://chapter-player.local:47831
```

The setup page intentionally has no password and must remain on a trusted private home network. Do not expose ports `80` or `47831` to the internet or configure router port forwarding for the player. See the [security policy](../SECURITY.md) for the complete network-safety guidance.

If the Pi is not connected to Wi-Fi, the setup service should start an open setup hotspot:

```text
Network:  Chapter-Setup
Password: none
Page:     http://10.42.0.1
```

Connect a phone or laptop to `Chapter-Setup`, then open `http://10.42.0.1`.

## Connect Audiobookshelf

On the setup page, enter:

- Audiobookshelf server URL, for example `https://books.example.com`.
- Username for the dedicated player user.
- Password for that user.

The password is sent to Audiobookshelf once. The player stores the returned user token, not the password.

If no library is selected, the player uses the user's default audiobook library or the first accessible audiobook library.

## Using The Player

- Turn the Select knob to browse books.
- Click the Select knob to choose.
- Turn the Volume knob to change volume.
- Click the Volume knob to mute or unmute.
- Hold the Volume knob for 10 seconds to show the setup address.
- When spoken navigation is enabled, Volume-knob changes are announced at 10% intervals, volume stops at 10%, and pressing the Volume knob does not mute the player.

## Updating Later

Run the installer again:

```bash
curl -fsSL https://raw.githubusercontent.com/chrismtopher/chapter/v0.3.11/scripts/install-raspberry-pi.sh | bash
sudo reboot
```

This reinstalls the tested `v0.3.11` release and refreshes the installed service files. To move to a later release, use the versioned command published for that release. For development builds, the installer also accepts `--release-ref REF` or the `CHAPTER_RELEASE_REF` environment variable.

After installing a release that includes device updates, open the **System** tab on the Chapter administration page. The player checks the public Chapter release tags and offers an **Update** button only when a newer stable version is available. Updating pauses playback, keeps the device configuration and listening state, installs the newest stable release, and restarts the player services. Keep the player powered on and connected to the internet until the administration page becomes available again.

## Troubleshooting

### SSH Does Not Connect

Make sure the Pi was flashed with SSH enabled, the hostname is `chapter-player`, and the Wi-Fi network is 2.4 GHz. If `.local` does not work, use the IP address from your router.

### OLED Is Blank

Check that SPI exists and that the `chapter` user has device permissions:

```bash
ls /dev/spidev*
groups chapter
```

Run the OLED test from the installed project:

```bash
cd /home/chapter/audiobookshelf-player
python3 -m abs_kids_player.oled_test
```

If `/dev/spidev0.0` is missing, rerun the installer and reboot. If the OLED test still stays blank, power off and re-check `VCC`, `GND`, `CLK`, `DIN`, `CS`, `DC`, and `RES`.

### No Sound

Check that ALSA sees the amp:

```bash
aplay -l
speaker-test -t wav -c 2
```

Press `Ctrl+C` to stop the speaker test.

If there is no sound card, rerun the installer and reboot. If there is a sound card but no audio, re-check the speaker wires and MAX98357A `VIN` and `GND`.

### Setup Page Does Not Open

Check the setup service and health endpoint:

```bash
systemctl status audiobookshelf-player-setup.service
curl http://localhost:47831/health
```

If the direct port works but `http://chapter-player.local` does not, check the port 80 proxy:

```bash
systemctl status audiobookshelf-player-port80-forward.service
curl http://localhost/health
```

### The Pi Shows The Setup Hotspot Instead Of Joining Wi-Fi

Connect to `Chapter-Setup`, open `http://10.42.0.1`, and enter the home Wi-Fi credentials. The setup page uses NetworkManager to switch from the hotspot to the selected Wi-Fi network.

### View Service Logs

```bash
journalctl -u audiobookshelf-player-setup.service -n 80
journalctl -u audiobookshelf-player-oled.service -n 80
tail -n 80 /home/chapter/audiobookshelf-player-oled.log
```

## References

- Raspberry Pi getting started guide: https://www.raspberrypi.com/documentation/computers/getting-started.html
- Raspberry Pi Zero 2 W hardware information: https://www.raspberrypi.com/documentation/computers/raspberry-pi.html
- Raspberry Pi configuration guide: https://www.raspberrypi.com/documentation/computers/configuration.html
- Adafruit MAX98357A Raspberry Pi setup: https://learn.adafruit.com/adafruit-max98357-i2s-class-d-mono-amp/raspberry-pi-usage

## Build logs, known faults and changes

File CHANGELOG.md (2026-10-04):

# Changelog

All notable changes to Chapter Player for Audiobookshelf are documented here.

## Unreleased

## [0.3.11] - 2026-10-04

- Announce Volume-knob adjustments at 10% intervals when spoken navigation is enabled.
- Keep Volume-knob adjustments at or above 10% and ignore the knob's mute press while spoken navigation is enabled.

## [0.3.10] - 2026-10-03

- Install and immediately enable BlueALSA so Bluetooth speakers and headphones work on clean Raspberry Pi OS Lite installations and after software updates.

## [0.3.9] - 2026-10-02

- Shorten the administration page title and heading to `Chapter Player`.

## [0.3.8] - 2026-10-02

- Start new and restored players with an empty podcast list so parents explicitly choose every podcast.
- Preserve resolver compatibility for previously supported podcast links without adding them to the library automatically.
- Reconcile the wiring and enclosure documentation with the released hardware, including USB-C power, fuse, amplifier, speaker, and control placement guidance.
- Expand the public-release safety notes and ignore locally generated promotional images.

## [0.3.7] - 2026-10-02

- Hide the redundant successful-update detail beneath the current software version.

## [0.3.6] - 2026-10-02

- Enlarge the library alphabet jump letter without changing title, author, or series alignment.

## [0.3.5] - 2026-10-02

- Keep the administration page on rapid update polling while services restart.
- Reload the administration page automatically after the new web service reports completion.

## [0.3.4] - 2026-10-02

- Pause playback and show the OLED update warning before installation work begins.
- Wait for an OLED-ready acknowledgement before starting the updater, with a bounded fallback timeout.

## [0.3.3] - 2026-10-02

- Silence paused and muted playback completely while keeping the I2S audio path active for pop-free resume.

## [0.3.2] - 2026-10-02

- Show an `UPDATING / DO NOT POWER OFF` warning on the OLED for the full software update.
- Refresh the administration page automatically when an update completes.

## [0.3.1] - 2026-10-02

- Consolidated update availability and confirmation controls into the Software Version section.

## [0.3.0] - 2026-10-02

- Added System-tab release checks and one-button stable software updates that preserve device settings.

## [0.2.2] - 2026-10-02

- Return from the library to the current playback controls after five seconds of inactivity while audio is playing.
- Refine the lightweight eSpeak NG spoken-navigation pacing and pitch while retaining its smoother default voice.

## [0.2.1] - 2026-10-02

- Documented the trusted-local-network security model and safe deployment boundaries.
- Added GitHub Actions coverage for the test suite, syntax checks, and Raspberry Pi OS Lite installer simulation.
- Made the installer simulation portable across macOS and Linux.

## [0.2.0] - 2026-10-02

- Added a web setting to order the player library by title or by author last name.
- Added optional offline spoken navigation for highlighted book titles and controls.
- Added the Chapter color logo and refined the tabbed administration interface.
- Added CSRF protection to setup-page forms and live player controls.
- Pinned the Raspberry Pi installer to versioned releases for reproducible installs.

## [0.1.0] - 2026-10-01

Initial public release.

- Raspberry Pi Zero 2 W/WH appliance interface with SH1122 OLED and two rotary controls.
- Audiobookshelf login, library browsing, playback, resume, and progress synchronization.
- Internal MAX98357A speaker output and Bluetooth audio support.
- Podcast support, sleep timer, screensavers, and web administration.
- Automated Raspberry Pi OS Lite installer, first-boot setup hotspot, and captive portal support.
- Printable enclosure files, wiring documentation, assembly references, and parts list.
- Shared storage ownership handling and an isolated installer simulation for clean-install validation.

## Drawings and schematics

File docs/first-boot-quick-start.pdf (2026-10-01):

# Chapter Quick Start

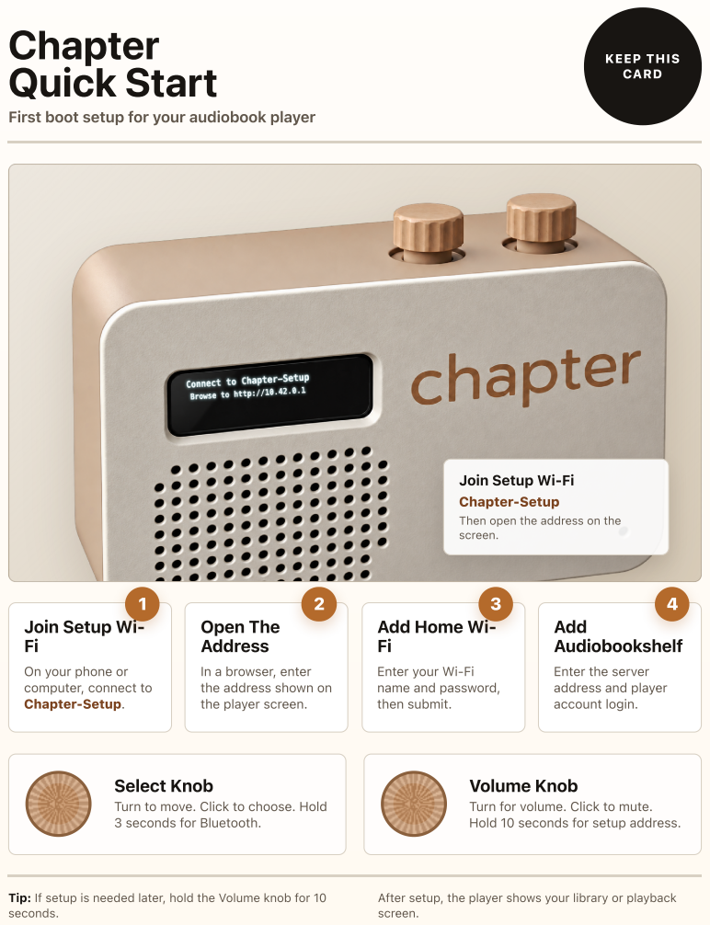
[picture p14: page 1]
KEEP THIS CARD

First boot setup for your audiobook player

Join Setup Wi-Fi
Chapter-Setup
Then open the address on the
screen.

Join Setup Wi-
On your phone or
computer, connect to
Chapter-Setup.

Open The
Address
In a browser, enter
the address shown on
the player screen.

Add Home Wi-
Enter your Wi-Fi
name and password,
then submit.

Add
Audiobookshelf
Enter the server
address and player
account login.

Select Knob
Turn to move. Click to choose. Hold
3 seconds for Bluetooth.

Volume Knob
Turn for volume. Click to mute.
Hold 10 seconds for setup address.

Tip: If setup is needed later, hold the Volume knob for 10
seconds.

After setup, the player shows your library or playback

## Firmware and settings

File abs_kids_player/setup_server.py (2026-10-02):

from __future__ import annotations

import argparse
import hmac
import html
import json
import secrets
import subprocess
import threading
import time
from dataclasses import replace
from http.server import BaseHTTPRequestHandler, ThreadingHTTPServer
from pathlib import Path
from typing import Callable
from urllib.parse import parse_qs, urlparse

from . import __version__
from .api import AudiobookshelfClient, AudiobookshelfError, client_from_config
from .bluetooth_audio import connected_bluetooth_audio_device
from .config import (
    LIBRARY_SORT_AUTHOR,
    LIBRARY_SORT_TITLE,
    MAX_SLEEP_TIMER_MINUTES,
    MIN_SLEEP_TIMER_MINUTES,
    SCREEN_SAVER_BOOKS,
    SCREEN_SAVER_CHAPTER,
    SCREEN_SAVER_CLOCK,
    SCREEN_SAVER_DIM_LEVELS,
    AppConfig,
    PodcastConfig,
    load_config,
    save_config,
    valid_library_sort_mode,
    valid_screen_saver_dim_percent,
    valid_screen_saver_mode,
    valid_sleep_timer_minutes,
)
from .library_cache import clear_cached_books
from .player_state import clear_last_playback
from .player_control import WebPlayerStatus, load_web_player_status, queue_web_player_command
from .podcast import PodcastError, resolve_podcast_config
from .software_update import (
    UPDATE_SERVICE_NAME,
    SoftwareUpdateState,
    save_update_state,
    update_status_payload,
    wait_for_update_display_ready,
)
from .wifi import (
    SETUP_HOTSPOT_SSID,
    SETUP_HOTSPOT_URL,
    WifiError,
    WifiStatus,
    connect_wifi,
    ensure_wifi_or_hotspot,
    forget_all_wifi_connections_and_start_hotspot,
    forget_current_wifi_and_start_hotspot,
    wifi_status,
)


DEFAULT_HOST = "0.0.0.0"
DEFAULT_PORT = 47831
WIFI_CHANGE_DELAY_SECONDS = 5.0
SYSTEM_ACTION_DELAY_SECONDS = 3.0
PLAYER_EVENT_POLL_SECONDS = 0.25
PLAYER_EVENT_TIME_SECONDS = 1.0
PLAYER_EVENT_HEARTBEAT_SECONDS = 10.0
MAX_POST_BODY_BYTES = 64 * 1024
CSRF_FIELD_NAME = "csrf_token"
LOGO_PATH = Path(__file__).resolve().parent / "assets" / "chapter-logo.png"


PAGE = """<!doctype html>
<html lang="en">
<head>
  <meta charset="utf-8">
  <meta name="viewport" content="width=device-width, initial-scale=1">
  <meta name="chapter-csrf-token" content="{csrf_token}">
  <title>Chapter Player</title>
  <link rel="icon" type="image/png" href="/assets/chapter-logo.png">
  <style>
    body {{
      font-family: system-ui, -apple-system, BlinkMacSystemFont, "Segoe UI", sans-serif;
      margin: 0;
      min-height: 100vh;
      background: #edf1ef;
      color: #1f292b;
    }}
    main {{
      width: min(92vw, 780px);
      margin: 28px auto 48px;
    }}
    .app-header {{
      display: flex;
      justify-content: space-between;
      gap: 24px;
      align-items: center;
      padding: 0 2px;
    }}
    .app-brand {{
      display: flex;
      align-items: center;
      gap: 14px;
      min-width: 0;
    }}
    .app-logo {{
      width: 84px;
      height: 63px;
      flex: 0 0 auto;
      object-fit: contain;
    }}
    .app-intro {{
      max-width: 500px;
      margin: 0;
      font-size: 0.95rem;
    }}
    .tabs {{
      display: flex;
      gap: 4px;
      margin-top: 22px;
      padding: 4px;
      overflow-x: auto;
      border: 1px solid #cfd9d6;
      border-radius: 8px;
      background: #f8faf9;
      scrollbar-width: none;
    }}
    .tabs::-webkit-scrollbar {{ display: none; }}
    .tab-button {{
      width: auto;
      min-width: 68px;
      min-height: 42px;
      flex: 1 0 auto;
      margin: 0;
      padding: 8px 4px;
      border: 0;
      border-radius: 6px;
      background: transparent;
      color: #586467;
      font-size: 0.8rem;
      font-weight: 750;
      cursor: pointer;
    }}
    .tab-button:hover {{
      background: #e9efed;
      color: #1f292b;
    }}
    .tab-button.is-active {{
      background: #234f50;
      color: #fff;
      box-shadow: 0 2px 7px rgba(26, 58, 59, 0.2);
    }}
    .tab-button:focus-visible,
    button:focus-visible,
    input:focus-visible,
    select:focus-visible {{
      outline: 3px solid #e8ad55;
      outline-offset: 2px;
    }}
    .tab-panel {{
      margin-top: 14px;
    }}
    .tab-panel[hidden] {{
      display: none;
    }}
    .connection-grid {{
      display: grid;
      grid-template-columns: repeat(2, minmax(0, 1fr));
      gap: 14px;
    }}
    .card {{
      background: #fff;
      border: 1px solid #d7dfdc;
      border-radius: 8px;
      padding: 24px;
      margin: 0;
      box-shadow: 0 10px 28px rgba(30, 49, 48, 0.09);
    }}
    h1 {{ margin: 0; font-size: 1.75rem; line-height: 1.15; }}
    h2 {{ margin: 0 0 14px; font-size: 1.05rem; }}
    p {{ color: #5d686b; line-height: 1.45; }}
    label {{ display: block; margin-top: 16px; font-weight: 700; }}
    input {{
      box-sizing: border-box;
      width: 100%;
      min-height: 44px;
      margin-top: 6px;
      padding: 8px 10px;
      border: 1px solid #b9c5c2;
      border-radius: 6px;
      font: inherit;
    }}
    button {{
      width: 100%;
      min-height: 48px;
      margin-top: 22px;
      border: 0;
      border-radius: 6px;
      background: #2e7d79;
      color: #fff;
      font: inherit;
      font-weight: 800;
      cursor: pointer;
    }}
    button:hover {{
      background: #256c68;
    }}
    button:disabled {{
      cursor: wait;
      opacity: 0.65;
    }}
    .playback-form button {{
      margin-top: 12px;
    }}
    .volume-form {{
      margin-top: 12px;
      display: grid;
      grid-template-columns: 28px 1fr 52px;
      gap: 10px;
      align-items: center;
    }}
    .volume-icon {{
      color: #20242a;
      font-size: 1.2rem;
      text-align: center;
      line-height: 1;
    }}
    .volume-percent {{
      color: #20242a;
      font-weight: 800;
      text-align: left;
      white-space: nowrap;
    }}
    .volume-slider {{
      padding: 0;
      margin-top: 0;
      min-height: 44px;
      border: 0;
      border-radius: 0;
      accent-color: #2e7d79;
    }}
    .message {{
      padding: 12px;
      border-radius: 6px;
      margin: 16px 0 0;
      background: #eef7f5;
      color: #164b47;
    }}
    .error {{
      background: #fbebeb;
      color: #842020;
    }}
    .hint {{
      font-size: 0.92rem;
    }}
    .settings-list {{
      margin-top: 12px;
      border: 1px solid #dfe6e3;
      border-radius: 8px;
      overflow: hidden;
    }}
    .settings-row {{
      display: grid;
      grid-template-columns: 1fr auto;
      gap: 16px;
      align-items: center;
      padding: 12px;
      border-top: 1px solid #dfe6e3;
    }}
    .settings-row:first-child {{ border-top: 0; }}
    .setting-name {{
      font-weight: 800;
    }}
    .setting-state {{
      color: #59616d;
      font-size: 0.88rem;
      margin-top: 3px;
    }}
    .toggle-form {{
      margin: 0;
    }}
    .toggle-button {{
      position: relative;
      width: 54px;
      height: 30px;
      min-height: 30px;
      margin: 0;
      padding: 0;
      display: block;
      box-sizing: border-box;
      border-radius: 999px;
      background: #a9aea9;
      overflow: hidden;
    }}
    .toggle-button::after {{
      content: "";
      position: absolute;
      top: 4px;
      left: 4px;
      width: 22px;
      height: 22px;
      border-radius: 50%;
      background: #fff;
      box-shadow: 0 1px 3px rgba(0, 0, 0, 0.28);
    }}
    .toggle-button.is-on {{
      background: #2e7d79;
    }}
    .toggle-button.is-on::after {{
      left: 28px;
    }}
    .select-form {{
      display: flex;
      gap: 8px;
      align-items: center;
      margin: 0;
    }}
    .settings-select {{
      min-width: 150px;
      border: 1px solid #d8d0c5;
      border-radius: 8px;
      padding: 8px 10px;
      background: #fff;
      color: #1f2933;
      font: inherit;
    }}
    .screen-saver-settings-form {{
      grid-column: 1 / -1;
      display: grid;
      grid-template-columns: minmax(0, 1fr) minmax(0, 0.8fr) auto;
      gap: 8px;
      align-items: end;
      margin: 2px 0 0;
    }}
    .screen-saver-settings-form label {{
      margin: 0;
      color: #59616d;
      font-size: 0.82rem;
    }}
    .screen-saver-settings-form .settings-select {{
      width: 100%;
      min-width: 0;
      margin-top: 4px;
    }}
    .settings-number {{
      width: 76px;
      min-height: 38px;
      margin: 0;
      padding: 7px 8px;
    }}
    .sleep-timer-content {{
      min-width: 0;
    }}
    .sleep-timer-duration-form {{
      display: flex;
      flex-wrap: wrap;
      gap: 8px;
      align-items: center;
      margin: 10px 0 0;
      color: #59616d;
      font-size: 0.88rem;
    }}
    .sleep-timer-duration-form .settings-number {{
      width: 68px;
    }}
    .small-button {{
      width: auto;
      min-height: 36px;
      padding: 8px 12px;
      border-radius: 8px;
      white-space: nowrap;
    }}
    .secondary {{
      background: #e8eeec;
      color: #20242a;
    }}
    .secondary:hover {{
      background: #dce6e2;
    }}
    .podcast-form {{
      margin-top: 12px;
    }}
    .podcast-table {{
      display: grid;
      gap: 10px;
    }}
    .podcast-row {{
      display: grid;
      grid-template-columns: 1fr auto;
      gap: 10px;
      align-items: end;
      padding: 10px;
      border: 1px solid #dfe6e3;
      border-radius: 8px;
      background: #f8faf9;
    }}
    .podcast-row input {{
      margin-top: 0;
    }}
    .podcast-meta {{
      color: #59616d;
      font-size: 0.84rem;
      margin-top: 5px;
    }}
    .podcast-actions {{
      display: flex;
      gap: 10px;
      align-items: center;
      justify-content: space-between;
      margin-top: 12px;
    }}
    .podcast-actions button {{
      margin-top: 0;
    }}
    .podcast-save-button {{
      width: auto;
      min-width: 132px;
    }}
    .system-actions {{
      border: 1px solid #dfe6e3;
      border-radius: 8px;
      overflow: hidden;
    }}
    .system-version {{
      display: grid;
      grid-template-columns: minmax(0, 1fr) auto;
      align-items: center;
      gap: 16px;
      margin-bottom: 16px;
      padding: 14px 16px;
      border: 1px solid #dfe6e3;
      border-radius: 8px;
      background: #f8faf9;
    }}
    .system-version-label {{
      color: #59616d;
      font-size: 0.9rem;
    }}
    .system-version-number {{
      display: block;
      margin-top: 2px;
      font-size: 1.05rem;
    }}
    .system-update-status {{
      display: block;
      margin-top: 3px;
      color: #59616d;
      font-size: 0.82rem;
      font-weight: 400;
    }}
    .system-update-description {{
      margin: 5px 0 0;
      font-size: 0.9rem;
    }}
    .system-version > button {{
      width: auto;
      min-width: 112px;
      min-height: 40px;
      margin: 0;
      padding: 8px 14px;
    }}
    .system-version > .confirmation-panel {{
      grid-column: 1 / -1;
    }}
    .system-action {{
      display: grid;
      grid-template-columns: minmax(0, 1fr) auto;
      gap: 14px;
      align-items: center;
      padding: 16px;
      border-top: 1px solid #dfe6e3;
    }}
    .system-action:first-child {{
      border-top: 0;
    }}
    .system-action h3 {{
      margin: 0;
      font-size: 1rem;
    }}
    .system-action p {{
      margin: 5px 0 0;
      font-size: 0.9rem;
    }}
    .system-action > button {{
      width: auto;
      min-width: 112px;
      min-height: 40px;
      margin: 0;
      padding: 8px 14px;
    }}
    .danger-button {{
      background: #a33a3a;
    }}
    .danger-button:hover {{
      background: #872f2f;
    }}
    .confirmation-panel {{
      grid-column: 1 / -1;
      padding: 14px;
      border: 1px solid #e5c6c6;
      border-radius: 6px;
      background: #fff7f7;
    }}
    .confirmation-panel.update-confirmation {{
      border-color: #b9d4d0;
      background: #f2f8f7;
    }}
    .confirmation-panel[hidden] {{
      display: none;
    }}
    .confirmation-panel strong {{
      display: block;
    }}
    .confirmation-actions {{
      display: flex;
      justify-content: flex-end;
      gap: 8px;
      margin-top: 12px;
    }}
    .confirmation-actions form {{
      margin: 0;
    }}
    .confirmation-actions button {{
      width: auto;
      min-width: 96px;
      min-height: 38px;
      margin: 0;
      padding: 8px 12px;
    }}
    .sr-only {{
      position: absolute;
      width: 1px;
      height: 1px;
      padding: 0;
      margin: -1px;
      overflow: hidden;
      clip: rect(0, 0, 0, 0);
      white-space: nowrap;
      border: 0;
    }}
    .status {{
      display: grid;
      grid-template-columns: 1fr;
      border: 1px solid #dfe6e3;
      border-radius: 8px;
      overflow: hidden;
    }}
    .status-row {{
      display: grid;
      grid-template-columns: minmax(140px, 180px) minmax(0, 1fr);
      gap: 16px;
      align-items: start;
      padding: 14px 16px;
      border-top: 1px solid #dfe6e3;
    }}
    .status-row:first-child {{ border-top: 0; }}
    .status-row:last-child {{
      padding: 16px;
    }}
    .status-label {{
      color: #59616d;
      font-size: 0.88rem;
    }}
    .status-value {{
      min-width: 0;
      overflow-wrap: anywhere;
    }}
    .status-value strong {{
      font-weight: 800;
    }}
    .now-playing-title {{
      font-weight: 800;
    }}
    .now-playing-meta {{
      color: #59616d;
      font-size: 0.92rem;
      margin-top: 4px;
    }}
    .hidden {{ display: none; }}
    .ok {{ color: #176c4f; }}
    .bad {{ color: #9b2c2c; }}
    code {{ background: #f1f1f1; padding: 2px 4px; border-radius: 4px; }}
    @media (max-width: 680px) {{
      main {{
        width: min(94vw, 520px);
        margin-top: 20px;
      }}
      .app-header {{
        display: block;
      }}
      .app-intro {{
        margin-top: 8px;
      }}
      .connection-grid {{
        grid-template-columns: 1fr;
      }}
      .card {{
        padding: 18px;
      }}
      .status {{
        grid-template-columns: 1fr;
      }}
      .status-row,
      .status-row:first-child {{
        grid-template-columns: 1fr;
        gap: 3px;
        border-top: 1px solid #dfe6e3;
      }}
      .status-row:first-child {{
        border-top: 0;
      }}
      .screen-saver-settings-form {{
        grid-template-columns: 1fr;
      }}
      .podcast-row {{
        grid-template-columns: 1fr;
      }}
      .podcast-row .small-button {{
        width: 100%;
      }}
      .system-action {{
        grid-template-columns: 1fr;
      }}
      .system-action > button {{
        width: 100%;
      }}
      .system-version {{
        grid-template-columns: 1fr;
      }}
      .system-version > button {{
        width: 100%;
      }}
      .confirmation-actions {{
        display: grid;
        grid-template-columns: 1fr 1fr;
      }}
      .confirmation-actions button {{
        width: 100%;
      }}
    }}
  </style>
</head>
<body>
  <main>
    <header class="app-header">
      <div class="app-brand">
        <img class="app-logo" src="/assets/chapter-logo.png" width="84" height="63" alt="">
        <h1>Chapter Player</h1>
      </div>
    </header>
    {message}
    <nav class="tabs" role="tablist" aria-label="Player administration">
      <button class="tab-button is-active" id="tab-overview" type="button" role="tab" aria-selected="true" aria-controls="panel-overview" data-tab-target="overview">Overview</button>
      <button class="tab-button" id="tab-settings" type="button" role="tab" aria-selected="false" aria-controls="panel-settings" tabindex="-1" data-tab-target="settings">Settings</button>
      <button class="tab-button" id="tab-podcasts" type="button" role="tab" aria-selected="false" aria-controls="panel-podcasts" tabindex="-1" data-tab-target="podcasts">Podcasts</button>
      <button class="tab-button" id="tab-connections" type="button" role="tab" aria-selected="false" aria-controls="panel-connections" tabindex="-1" data-tab-target="connections">Setup</button>
      <button class="tab-button" id="tab-system" type="button" role="tab" aria-selected="false" aria-controls="panel-system" tabindex="-1" data-tab-target="system">System</button>
    </nav>
    <div class="tab-panel" id="panel-overview" role="tabpanel" aria-labelledby="tab-overview" data-tab-panel="overview">
      {status_panel}
    </div>
    <div class="tab-panel" id="panel-settings" role="tabpanel" aria-labelledby="tab-settings" data-tab-panel="settings" hidden>
      {settings_card}
    </div>
    <div class="tab-panel" id="panel-podcasts" role="tabpanel" aria-labelledby="tab-podcasts" data-tab-panel="podcasts" hidden>
      {podcasts_card}
    </div>
    <div class="tab-panel connection-grid" id="panel-connections" role="tabpanel" aria-labelledby="tab-connections" data-tab-panel="connections" hidden>
      {wifi_card}
      <section class="card" aria-labelledby="audiobookshelf-heading">
        <h2 id="audiobookshelf-heading">Audiobookshelf</h2>
        <p class="hint">The password is sent only to your Audiobookshelf server. This player stores the returned user token.</p>
        <form method="post" action="/login">
          {csrf_input}
          <label for="server_url">Audiobookshelf server URL</label>
          <input id="server_url" name="server_url" value="{server_url}" placeholder="https://books.example.com" required>

          <label for="username">Username</label>
          <input id="username" name="username" autocomplete="username" required>

          <label for="password">Password</label>
          <input id="password" name="password" type="password" autocomplete="current-password" required>
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

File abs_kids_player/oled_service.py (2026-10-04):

from __future__ import annotations

import argparse
import faulthandler
import math
import queue
import signal
import threading
import time
import traceback
from dataclasses import dataclass, replace
from datetime import datetime
from pathlib import Path
from typing import Callable

from .api import AudiobookshelfClient, AudiobookshelfError, client_from_config
from .appliance_io import AmpShutdownPin, InputEvent, Ky040Pins, NavigationRotaryInput, Sh1122Display, VolumeRotaryInput
from .audio import (
    DEFAULT_MIXER_CONTROLS,
    AudioError,
    VolumeState,
    change_volume,
    play_boot_chime,
    play_control_click,
    toggle_mute,
)
from .bluetooth_audio import (
    BluetoothActionResult,
    BluetoothDevice,
    bluetooth_powered,
    connected_bluetooth_audio_device,
    pair_bluetooth_device,
    preferred_bluetooth_alsa_device,
    scan_bluetooth_devices,
    set_bluetooth_power,
    unpair_connected_bluetooth_audio_device,
)
from .config import (
    DEFAULT_SCREEN_SAVER_DIM_PERCENT,
    LIBRARY_SORT_AUTHOR,
    LIBRARY_SORT_TITLE,
    SCREEN_SAVER_BOOKS,
    SCREEN_SAVER_CHAPTER,
    SCREEN_SAVER_CLOCK,
    AppConfig,
    load_config,
)
from .library_cache import load_cached_books, save_cached_books
from .models import Book
from .network import get_lan_ip
from .player_control import WebPlayerStatus, consume_web_player_commands, save_web_player_status
from .player_state import clear_last_playback, load_player_state, save_last_playback
from .podcast import (
    PodcastError,
    PodcastProgressClient,
    latest_podcast_session,
    podcast_by_book_id,
    podcast_books,
)
from .playback import GStreamerPlayback, PlaybackError
from .rotary_ui import (
    ApplianceMenu,
    CommandType,
    DisplayFrame,
    HomeFrame,
    MenuCommand,
    ScreenSaverFrame,
    SplashFrame,
    SpokenSelection,
    TwoLineFrame,
    VolumeFrame,
    WifiSetupFrame,
    author_sort_text,
    book_is_podcast,
    title_sort_text,
)
from .spoken_navigation import SpokenNavigationFeedback
from .software_update import load_update_state, mark_update_display_ready, update_state_is_active
from .wifi import SETUP_HOTSPOT_SSID, SETUP_HOTSPOT_URL, WifiStatus, wifi_status


DEFAULT_REFRESH_SECONDS = 0.14
DEFAULT_STATUS_REFRESH_SECONDS = 2.0
DEFAULT_SPLASH_SECONDS = 0.5
DEFAULT_STARTUP_NETWORK_GRACE_SECONDS = 30.0
DEFAULT_HOME_REFRESH_SECONDS = 60.0
DEFAULT_TITLE_SCROLL_DELAY_SECONDS = 2.0
DEFAULT_TITLE_SCROLL_PX_PER_SECOND = 16.0
DEFAULT_TITLE_SCROLL_LOOP_PAUSE_SECONDS = 2.0
DEFAULT_VOLUME_OVERLAY_SECONDS = 3.0
DEFAULT_IP_OVERLAY_SECONDS = 5.0
DEFAULT_SCREEN_SAVER_IDLE_SECONDS = 300.0
DEFAULT_SCREEN_SAVER_FRAMES_PER_SECOND = 8.0
DEFAULT_UNMUTE_VOLUME_PERCENT = 10
DEFAULT_BOOT_SPLASH_HANDOFF_PATH = "/tmp/audiobookshelf-player-oled-starting"
DEFAULT_BOOT_SPLASH_HANDOFF_SETTLE_SECONDS = 0.3
DEFAULT_PLAYBACK_STATE_SAVE_SECONDS = 5.0
DEFAULT_CONTROL_CLICK_MIN_INTERVAL_SECONDS = 0.045
DEFAULT_SLEEP_CONFIRM_SECONDS = 30
DEFAULT_ACTIVE_BRIGHTNESS_PERCENT = 100
DEFAULT_RUNTIME_CONFIG_REFRESH_SECONDS = 1.0
DEFAULT_SOFTWARE_UPDATE_REFRESH_SECONDS = 0.2
DEFAULT_WAKE_INPUT_QUIET_SECONDS = 0.35
VOLUME_STEP_PERCENT = 5
SPOKEN_VOLUME_INTERVAL_PERCENT = 10
SPOKEN_NAVIGATION_MIN_VOLUME_PERCENT = 10
BOOK_LOADING_FRAME = TwoLineFrame("Grabbing that book", "from the shelf...")
BLUETOOTH_PAIRING_FRAME = TwoLineFrame("Pair Bluetooth", "Put device in pair mode")
BLUETOOTH_POWER_FRAME = TwoLineFrame("Bluetooth", "Updating...")
SOFTWARE_UPDATE_FRAME = TwoLineFrame("UPDATING", "DO NOT POWER OFF")


class PlaybackCommandResult:
    def __init__(
        self,
        session=None,
        client=None,
        error_frame: DisplayFrame | None = None,
    ) -> None:
        self.session = session
        self.client = client
        self.error_frame = error_frame


class BookLoadResult:
    def __init__(
        self,
        books: list[Book] | None = None,
        error_frame: DisplayFrame | None = None,
        generation: int = 0,
    ) -> None:
        self.books = books
        self.error_frame = error_frame
        self.generation = generation


@dataclass(frozen=True)
class BluetoothStatusResult:
    enabled: bool
    connected: bool


@dataclass
class ListeningSleepTimer:
    listened_seconds: float = 0.0
    session_id: str = ""
    prompt_deadline: float = 0.0
    sleeping: bool = False
    sleep_started_at: float = 0.0

    @property
    def prompt_active(self) -> bool:
        return self.prompt_deadline > 0

    def update(
        self,
        now: float,
        elapsed_seconds: float,
        enabled: bool,
        minutes: int,
        session_id: str,
        is_playing: bool,
    ) -> str:
        if not enabled or not session_id:
            was_active = self.prompt_active or self.sleeping
            self.reset(session_id)
            return "cancel" if was_active else ""

        if session_id != self.session_id:
            self.reset(session_id)

        if self.sleeping:
            return ""

        if self.prompt_active:
            if now >= self.prompt_deadline:
                self.prompt_deadline = 0.0
                self.sleeping = True
                self.sleep_started_at = now
                return "sleep"
            return ""

        if is_playing:
            self.listened_seconds += max(0.0, elapsed_seconds)
        if self.listened_seconds < max(1, minutes) * 60:
            return ""

        self.prompt_deadline = now + DEFAULT_SLEEP_CONFIRM_SECONDS
        return "prompt"

    def countdown_seconds(self, now: float) -> int:
        if not self.prompt_active:
            return 0
        return max(0, math.ceil(self.prompt_deadline - now))

    def confirm(self) -> None:
        self.listened_seconds = 0.0
        self.prompt_deadline = 0.0
        self.sleeping = False
        self.sleep_started_at = 0.0

    def wake(self) -> bool:
        if not self.sleeping:
            return False
        self.confirm()
        return True

    def reset(self, session_id: str = "") -> None:
        self.listened_seconds = 0.0
        self.session_id = session_id
        self.prompt_deadline = 0.0
        self.sleeping = False
        self.sleep_started_at = 0.0


def bluetooth_result_frame(result: BluetoothActionResult) -> DisplayFrame:
    if result.success and result.devices:
        return TwoLineFrame("Choose device", "Scroll and click")
    if result.success and result.connected is False:
        return TwoLineFrame("Bluetooth unpaired", "Internal speaker")
    if result.success and result.device_name:
        return TwoLineFrame("Paired Successfully!", result.device_name)
    if result.success:
        return TwoLineFrame("Bluetooth", "On" if result.enabled else "Off")
    return TwoLineFrame("Bluetooth failed", result.message)


def bluetooth_scanning_frame(now: float) -> TwoLineFrame:
    dots = "." * ((int(now * 2) % 3) + 1)
    return TwoLineFrame("Put your device in pairing mode", f"Searching{dots}")
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

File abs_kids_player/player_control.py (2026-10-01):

from __future__ import annotations

import json
import os
import time
import uuid
from dataclasses import asdict, dataclass
from pathlib import Path
from typing import Any

from .storage import ensure_storage_directory, finalize_storage_file


STATE_DIR = Path.home() / ".local" / "state" / "abs-kids-player"
STATUS_PATH = STATE_DIR / "web-player-status.json"
COMMANDS_PATH = STATE_DIR / "web-player-commands.json"


@dataclass(frozen=True)
class WebPlayerStatus:
    title: str = ""
    author: str = ""
    current_time: float = 0
    duration: float = 0
    is_playing: bool = False
    volume_percent: int = 50
    muted: bool = False
    updated_at: float = 0

    @property
    def has_session(self) -> bool:
        return bool(self.title.strip())


@dataclass(frozen=True)
class WebPlayerCommand:
    action: str
    value: int | None = None
    id: str = ""
    created_at: float = 0


def save_web_player_status(status: WebPlayerStatus) -> None:
    path = status_path()
    ensure_storage_directory(path.parent)
    data = asdict(status)
    data["updated_at"] = time.time()
    path.write_text(json.dumps(data, indent=2), encoding="utf-8")
    finalize_storage_file(path)


def load_web_player_status() -> WebPlayerStatus:
    try:
        data = json.loads(status_path().read_text(encoding="utf-8"))
    except (OSError, json.JSONDecodeError):
        return WebPlayerStatus()

    return WebPlayerStatus(
        title=str(data.get("title", "")),
        author=str(data.get("author", "")),
        current_time=float(data.get("current_time") or 0),
        duration=float(data.get("duration") or 0),
        is_playing=bool(data.get("is_playing")),
        volume_percent=clamp_int(data.get("volume_percent"), 0, 100, 50),
        muted=bool(data.get("muted")),
        updated_at=float(data.get("updated_at") or 0),
    )


def queue_web_player_command(action: str, value: int | None = None) -> WebPlayerCommand:
    command = WebPlayerCommand(
        action=action,
        value=value,
        id=uuid.uuid4().hex,
        created_at=time.time(),
    )
    commands = read_command_data()
    commands.append(asdict(command))
    write_command_data(commands)
    return command


def consume_web_player_commands() -> list[WebPlayerCommand]:
    commands = [
        WebPlayerCommand(
            action=str(item.get("action", "")),
            value=item.get("value") if isinstance(item.get("value"), int) else None,
            id=str(item.get("id", "")),
            created_at=float(item.get("created_at") or 0),
        )
        for item in read_command_data()
        if isinstance(item, dict)
    ]
    write_command_data([])
    return [command for command in commands if command.action]


def read_command_data() -> list[dict[str, Any]]:
    try:
        data = json.loads(commands_path().read_text(encoding="utf-8"))
    except (OSError, json.JSONDecodeError):
        return []
    return data if isinstance(data, list) else []


def write_command_data(commands: list[dict[str, Any]]) -> None:
    path = commands_path()
    ensure_storage_directory(path.parent)
    path.write_text(json.dumps(commands, indent=2), encoding="utf-8")
    finalize_storage_file(path)


def status_path() -> Path:
    configured_path = os.environ.get("ABS_KIDS_PLAYER_WEB_STATUS_PATH", "").strip()
    if configured_path:
        return Path(configured_path).expanduser()
    configured_dir = os.environ.get("ABS_KIDS_PLAYER_STATE_DIR", "").strip()
    if configured_dir:
        return Path(configured_dir).expanduser() / STATUS_PATH.name
    return STATUS_PATH


def commands_path() -> Path:
    configured_path = os.environ.get("ABS_KIDS_PLAYER_WEB_COMMANDS_PATH", "").strip()
    if configured_path:
        return Path(configured_path).expanduser()
    configured_dir = os.environ.get("ABS_KIDS_PLAYER_STATE_DIR", "").strip()
    if configured_dir:
        return Path(configured_dir).expanduser() / COMMANDS_PATH.name
    return COMMANDS_PATH


def clamp_int(value: object, minimum: int, maximum: int, fallback: int) -> int:
    try:
        parsed = int(value)
    except (TypeError, ValueError):
        return fallback
    return min(max(parsed, minimum), maximum)

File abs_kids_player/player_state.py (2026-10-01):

from __future__ import annotations

import json
import os
import time
from dataclasses import asdict, dataclass
from pathlib import Path

from .storage import ensure_storage_directory, finalize_storage_file


STATE_DIR = Path.home() / ".local" / "state" / "abs-kids-player"
STATE_PATH = STATE_DIR / "player-state.json"


@dataclass(frozen=True)
class LastPlaybackState:
    book_id: str
    title: str
    current_time: float = 0
    updated_at: float = 0

    @property
    def is_ready(self) -> bool:
        return bool(self.book_id.strip() and self.title.strip())


def load_player_state() -> LastPlaybackState | None:
    path = state_path()
    if not path.exists():
        return None

    try:
        data = json.loads(path.read_text(encoding="utf-8"))
    except (OSError, json.JSONDecodeError):
        return None

    state = LastPlaybackState(
        book_id=str(data.get("book_id", "")),
        title=str(data.get("title", "")),
        current_time=float(data.get("current_time") or 0),
        updated_at=float(data.get("updated_at") or 0),
    )
    return state if state.is_ready else None


def save_last_playback(book_id: str, title: str, current_time: float, now: float | None = None) -> None:
    state = LastPlaybackState(
        book_id=book_id,
        title=title,
        current_time=max(0.0, current_time),
        updated_at=time.time() if now is None else now,
    )
    if not state.is_ready:
        return

    path = state_path()
    ensure_storage_directory(path.parent)
    path.write_text(json.dumps(asdict(state), indent=2), encoding="utf-8")
    finalize_storage_file(path)


def clear_last_playback() -> None:
    try:
        state_path().unlink(missing_ok=True)
    except OSError:
        pass


def state_path() -> Path:
    configured_path = os.environ.get("ABS_KIDS_PLAYER_STATE_PATH", "").strip()
    if configured_path:
        return Path(configured_path).expanduser()

    configured_dir = os.environ.get("ABS_KIDS_PLAYER_STATE_DIR", "").strip()
    if configured_dir:
        return Path(configured_dir).expanduser() / "player-state.json"

    return STATE_PATH

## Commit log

2026-10-01 Add Raspberry Pi installer script
2026-10-01 Make Raspberry Pi guide installer-first
2026-10-01 Add printable case STL files
    [chapter-case-back-v5.stl, chapter-case-front-logo-v5.stl, chapter-case-front-v5.stl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]
2026-10-01 Update front case STL
    [chapter-case-front-logo-v5.stl, chapter-case-front-v5.stl]
2026-10-01 Add case back assembly diagram
2026-10-01 Correct case hardware layout diagrams
2026-10-01 Use CAD views for case diagrams
2026-10-01 Refine case diagram callouts
2026-10-01 Use JPGs for case diagrams
2026-10-01 Add foot callout to case diagram
2026-10-01 Document power fuse and wiring parts
2026-10-01 Add front cover OLED assembly diagram
2026-10-01 Add printable quick start exports
2026-10-01 Use realistic quick start device art
2026-10-01 Match quick start screen text to setup frame
2026-10-01 Bake quick start screen text into device image
2026-10-01 Document front power indicator LED
2026-10-01 Specify enclosure fastener quantities
2026-10-01 Add case top control label reference
2026-10-02 Secure and pin v0.2.0 release
2026-10-02 Simplify current version status
